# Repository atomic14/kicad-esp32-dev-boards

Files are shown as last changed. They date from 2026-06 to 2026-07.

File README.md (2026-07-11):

# ESP Dev-Board Generator

Generates canonical "basic dev board" KiCad schematics for the Espressif modules
that have a **PCB antenna + native USB** (12 modules across S2/S3/C3/C5/C6/H2).
Each board takes a shared skeleton (USB-C, 3V3 LDO, BOOT/EN buttons, LEDs) and
adds the module symbol + two break-out pin headers, wired entirely with net
labels (no routing). Output is a complete, openable KiCad project per module.

> **Why / design rationale:** see [`DECISIONS.md`](DECISIONS.md). This file is
> the *operational* guide; DECISIONS.md is the *why*.

## What it builds

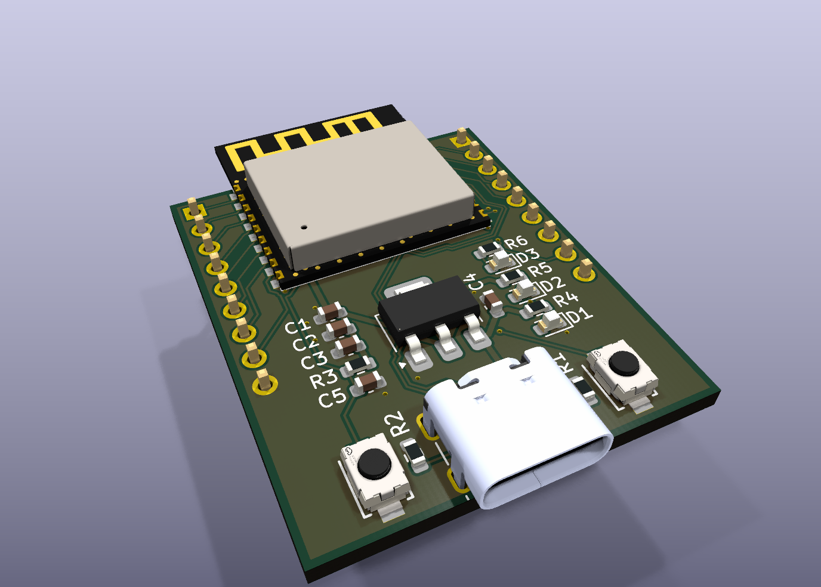
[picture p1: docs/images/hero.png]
ESP32-C3-WROOM-02 dev board, 3D render


Every board is the same canonical dev board — USB-C, 3V3 LDO, BOOT/EN buttons,
power + user LEDs — plus the module and its full GPIO break-out on two headers
(that's the ESP32-C3-WROOM-02 above; every component carries its 3D model, so
each board renders assembly-ready). The views below are to scale (equal
mm-per-pixel; each label carries the board's WxH):

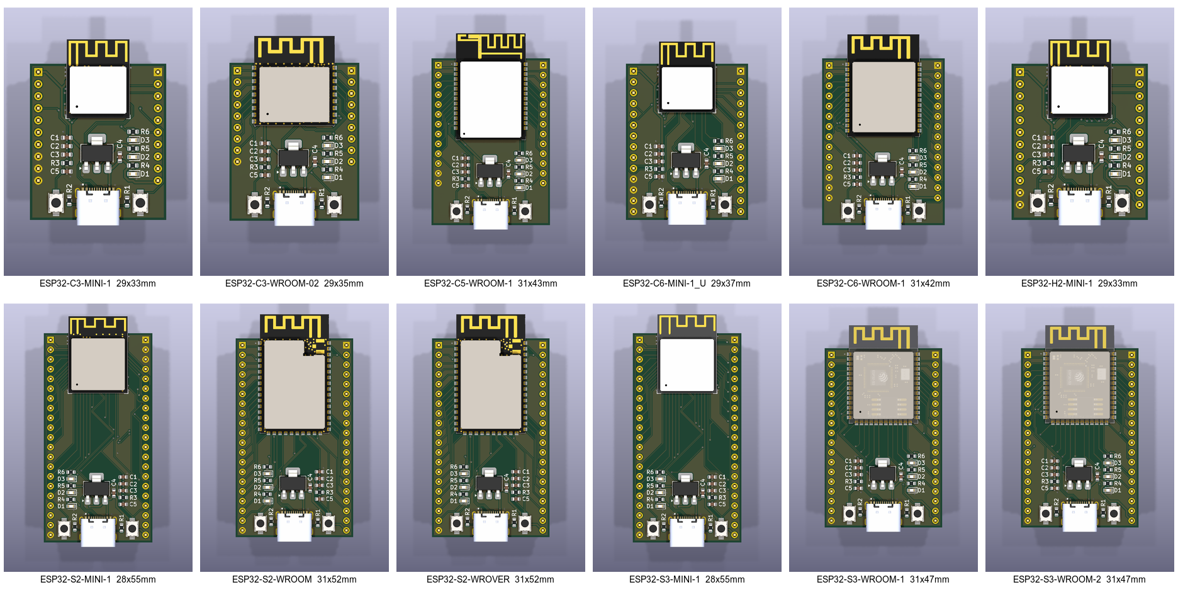
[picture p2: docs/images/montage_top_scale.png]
All 12 boards, front, to scale


The back silk labels every header pin with its net name and carries a vertical
board identifier — the module name plus the git revision that generated it
(`git describe --tags --always --dirty`):

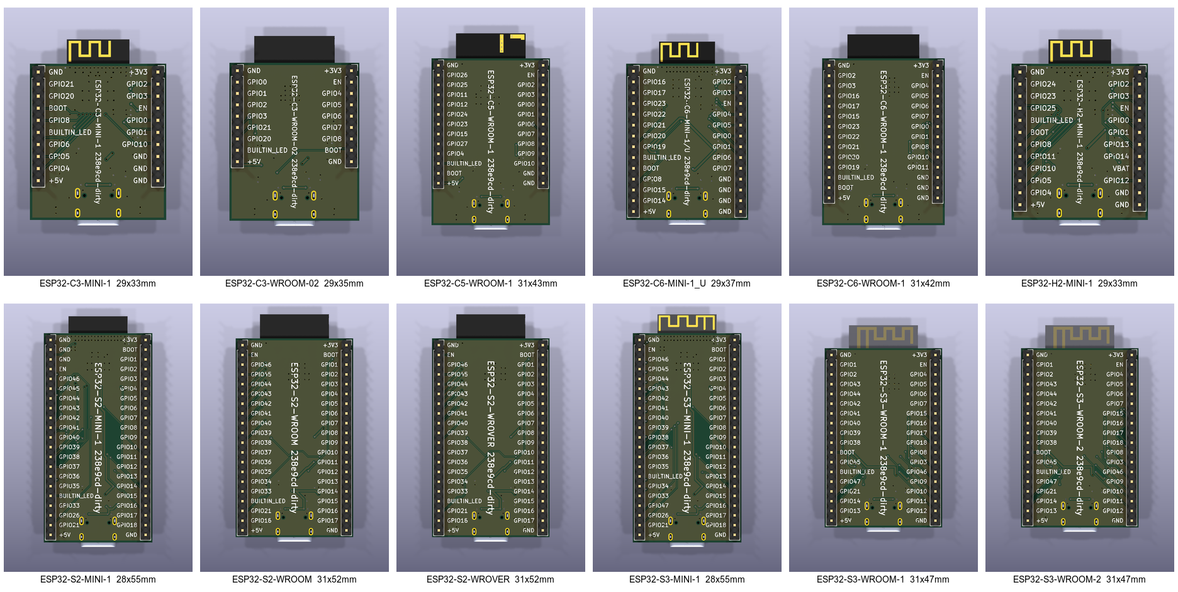
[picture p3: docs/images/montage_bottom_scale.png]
All 12 boards, back, to scale


These are snapshots of what `make.py --render` writes to `build/`: seven
montages (`montage_{top,top_bare,bottom}[_scale].png` — auto-fit and to-scale —
plus `montage_hero.png`) and a perspective `render_hero.png` per board under
`build/<MODULE>/`. To refresh them:

```bash
cp build/montage_{top,bottom}_scale.png docs/images/
cp build/ESP32-C3-WROOM-02/render_hero.png docs/images/hero.png
```

## Prerequisites (per machine)

1. **KiCad 10.x** installed (the schematics use the v10 file format).
2. **Espressif KiCad libraries installed *for that same KiCad version*** via
   KiCad's **Plug-in & Content Manager** (open KiCad 10 → PCM → search
   "Espressif" → install "Espressif KiCad Libraries" → Apply). This provides the
   `PCM_Espressif` symbol/footprint libraries. *This is the one manual install
   step and must be done before running anything.*
   > ⚠️ The addon is installed **per KiCad major version**. Having it for
   > KiCad 8/9 does **not** count if you run KiCad 10 — the PCM stores each
   > version's addons under a separate `Documents/KiCad/<version>/3rdparty` dir.
   > `resolve_library.py` pins to your running `kicad-cli` version and will
   > **hard-fail** (with these instructions) if the addon is missing for it,
   > rather than silently mixing libraries across versions.
3. **[uv](https://docs.astral.sh/uv/)** (Python package manager).
4. **[KiCadRoutingTools](https://github.com/atomic14/KiCadRoutingTools)** (our
   fork, `dev-board-fixes` branch) cloned as a **sibling** of this repo (or set
   `$KICAD_ROUTING_TOOLS`), with its Rust router built:
   ```bash
   git clone -b dev-board-fixes https://github.com/atomic14/KiCadRoutingTools.git ../KiCadRoutingTools
   (cd ../KiCadRoutingTools && python3 build_router.py --from-source)  # needs cargo
   ```
   Only needed for the *route* stage — build/render/fab work without it.
5. Internet access to `https://www.atomic14.com/esp32/` (only needed when
   curating a new module's `board.yaml`).

`resolve_library.py` auto-locates KiCad on macOS / Linux / Windows. If it can't,
set `ESPRESSIF_3RDPARTY` (the `<kicad>/3rdparty` dir) and/or `KICAD_CLI`
(path to `kicad-cli`) and re-run it. **Re-run it after any KiCad upgrade /
reinstall** — `library.json` records absolute, version-specific paths, and
`make.py` will refuse to run (pointing you back here) if those paths go stale.

## Quick start

```bash
uv sync                                   # restore the Python env (pinned in uv.lock)
uv run python scripts/resolve_library.py  # detect KiCad/libraries -> library.json (once/machine)
uv run python scripts/make.py             # build + route every board (THE command)
```

`make.py` is the one front door — it chains clean → build → route → render:

```bash
uv run python scripts/make.py            # build + route all modules
uv run python scripts/make.py --clean    # wipe prior output first
uv run python scripts/make.py --render    # also render the 3D montages
uv run python scripts/make.py --fab       # also export fab zips (Gerbers + drill)
uv run python scripts/make.py --all       # clean + build + route + render + fab
uv run python scripts/make.py --no-route  # build only
```

Generated boards land in `out/<MODULE>/<MODULE>.kicad_sch` (+ `.kicad_pro`,
`.kicad_pcb`); validation artifacts (ERC JSON, PDF render) in `build/<MODULE>/`.
Open any `out/<MODULE>/<MODULE>.kicad_pro` in KiCad. Both `out/` and `build/` are
git-ignored and fully disposable — `make.py --clean` (or `clean.py`) just removes
them. The curated source in `modules/` is never touched.

## Repository layout

```
DECISIONS.md            design decisions + rationale (read for the "why")
library.json            GENERATED per machine by resolve_library.py (git-ignore-able)
pyproject.toml/uv.lock  pinned Python env (kicad-skip, sexpdata, pyyaml)
baseline-left-en/       skeleton KiCad project (INPUT — never edit); EN button on the left
baseline-right-en/      same skeleton mirrored, EN on the right — generator auto-picks per module
  BasicEsp32Footprints.pretty/, 3d-models/, fp-lib-table   project-local footprints + 3D models
scripts/                orchestrators (run these); scripts/lib/ holds the per-module primitives
modules/<MODULE>/        CURATED SOURCE only (committed) — clean never touches it
  board.yaml            the only hand-authored file (see below)
  pinout.json           extracted from the symbol (never hand-edit); cached source
out/<MODULE>/            GENERATED board (git-ignored, disposable: rm -rf out)
  <MODULE>.kicad_sch/pro/pcb   the board — open <MODULE>.kicad_pro in KiCad
  fp-lib-table + *.pretty/ + asset dirs   copied from baseline
  route_debug/          per-stage routing snapshots for inspection
  fab/ + <MODULE>-fab.zip   Gerbers + Excellon drill; the .zip is fab-ready
build/<MODULE>/          GENERATED validation artifacts (git-ignored, disposable)
docs/AGENT_END_TO_END.md  agent spec: curate every board.yaml, then pilot-verify one module
docs/images/             committed montage snapshots referenced by this README

```

## The pipeline (`scripts/`)

**Orchestrators** — the top-level commands you run:

| Script | Role | Deterministic? |
|---|---|---|
| `make.py` | **THE command** — chains clean → build → route → render → fab (flags toggle stages) | ✅ |
| `resolve_library.py` | Find KiCad libs + `kicad-cli` → `library.json` | ✅ run once/machine |
| `build_all.py [--clean]` | extract → build → validate every curated module | ✅ |
| `route_all.py [--no-diff]` | autoroute every board (diff-pair with single-ended fallback; writes back in place) + DRC | ✅ |
| `render_boards.py` | 3D montages of every board → `build/` (top, top-bare/no-components, bottom — each auto-fit AND to-scale — plus a perspective hero shot per board) | ✅ |
| `fab_all.py` | Gerber + Excellon drill zip per board → `out/<M>/<M>-fab.zip` | ✅ |
| `clean.py` | remove generated output for a fresh run — just `rm -rf out build`; the curated `modules/` source is never touched | ✅ |

**Primitives** (`scripts/lib/`) — operate on one module; called by the orchestrators, rarely run directly:

| Script | Role |
|---|---|
| `extract_pinout.py "<MODULE>"` | Parse the symbol → `modules/<m>/pinout.json` |
| `footprint_edges.py "<MODULE>"` | Physical pin edges from the footprint |
| `build_board.py "<MODULE>"` | **The generator**: module + perimeter-split headers + labels + footprints + project files (copies the baseline's `fp-lib-table` and all asset dirs — `*.pretty` footprint libs, `3d-models/`, etc.) |
| `route_board.py "<MODULE>"` | Autoroute one board (USB-C fine neck, signals, GND pour) |
| `place_pcb.py` / `gnd_finish.py` / `gnd_prestitch.py` | PCB placement + GND-pour fill/stitch helpers (prestitch protects GND pads before routing) |
| `validate.py <sch>` | ERC delta vs baseline + PDF render |
| `fab_export.py "<MODULE>"` | Gerbers (`--check-zones` refills pours) + Excellon drill → zipped fab package |

**~95% of the work is fully scripted.** The only step needing human/agent
judgement is curating each module's `board.yaml`.

## Adding / re-curating a module

`board.yaml` is the one hand-authored file. Most wiring is auto-derived (power,
GND, EN, USB→D±, GPIO→`GPIOxx` labels). You decide:

- **`do_not_break_out`**: pins that must NOT be exposed — internal flash/PSRAM
  and any pin the [atomic14 module page](https://www.atomic14.com/esp32/modules/)
  marks as a hard "do not use". Strapping / JTAG / UART / USB pins are still
  broken out (documented in `notes`, not excluded).
- **`strapping` / `input_only`**: GPIO numbers (curated from the atomic14 page /
  datasheet) that are sampled at reset or have no output driver. They're *still*
  broken out — these lists only steer the on-board LED away from unsafe pins.
- **`builtin_led`**: the GPIO the skeleton's on-board LED attaches to. The
  generator routes it to the **safe pad physically nearest the LED** on the laid-out
  PCB (shortest trace); `build_board.py pick_builtin_led()` computes exactly that,
  and the build **hard-errors** if `builtin_led` names a strapping / input-only /
  non-broken-out pin. "Safe" = I/O-capable, non-strapping, broken-out GPIO.
- **`boot`**: the download/boot strapping GPIO the on-board BOOT button pulls low —
  GPIO0 on Xtensa (ESP32/-S2/-S3), GPIO9 on most RISC-V (-C3/-C6/-H2), GPIO28 on
  -C5. Varies per module, so the generator aliases the skeleton's `BOOT` net onto it.

```yaml
module: ESP32-S3-WROOM-1
symbol: PCM_Espressif:ESP32-S3-WROOM-1
do_not_break_out: [SPIDQS, SPIIO6, SPIIO7]   # octal flash/PSRAM, must not expose
overrides: {}
strapping: [0, 3, 45, 46]   # sampled at reset — unsafe for the LED (GPIO45 = VDD_SPI)
input_only: []              # no output driver
builtin_led: GPIO48         # safe GPIO pad nearest the on-board LED (NOT GPIO45, a strap)
boot: GPIO0                 # download/boot strapping pin the BOOT button pulls low
notes: >
  Source: https://www.atomic14.com/esp32/modules/esp32-s3-wroom-1/ ...
```

> ⚠️ Curation is **symbol-specific, not name-based**: e.g. `SPIIO6/7`/`SPIDQS`
> are reserved on the octal S3-WROOM-1, but are *freely-usable GPIO* on the quad
> S3-MINI-1 (and are NC, so absent, on the WROOM-2). Check the atomic14 page;
> don't blindly exclude by name.

Then: `uv run python scripts/lib/build_board.py "<MODULE>"` and
`uv run python scripts/lib/validate.py out/<m>/<m>.kicad_sch`, and **open the
rendered PDF** — the visual check catches things ERC can't (it once passed a
board whose USB pins were unconnected).

## Validation

`validate.py` gate = **no new ERROR-severity ERC violations vs the baseline**.
New *warnings* are expected and fine (notably the `pin_to_pin` from connecting
`GPIO0` to the boot button — the EasyEDA button symbol uses `Unspecified` pin
types). The baseline itself has ~58 pre-existing violations, so the bar is the
*delta*, not zero. Always also eyeball the PDF render.

## Fabrication

`make.py --fab` (or `fab_all.py`, or `fab_export.py "<M>"` for one) exports a
fab-ready package per board to `out/<M>/<M>-fab.zip` (loose files also in
`out/<M>/fab/`). The zip holds the standard 2-layer Gerber set (`F.Cu B.Cu`,
paste, silkscreen, mask, `Edge.Cuts`) plus an Excellon drill file, drill map,
and `.gbrjob` — flat-zipped, ready to upload to JLCPCB / PCBWay / most houses.

Key detail: the Gerber export runs with `--check-zones`, which **refills the
copper pours during export**, so the GND plane is always present in the copper
Gerbers even though headless tools save boards with empty fills — otherwise
you'd ship a board with no ground plane. Coordinates use an absolute origin for
both Gerbers and drill so they align. If your fab wants PTH/NPTH drills split,
add `--excellon-separate-th` in `fab_export.py` (currently combined).

**Silk order-number marker.** `build_board` drops a small F-silk text
(`SILK_MARKER_TEXT`, default `"WayWayWay"`) centred in the clear band just above
the module's bottom pin row — under the body, so it's hidden once the module is
soldered down, and never on exposed copper (its real rendered bounding box is
clearance-checked against every pad, and the size auto-shrinks on tight modules).
This gives the board house a designated spot for its order number instead of it
landing on visible silk. Change the text via `SILK_MARKER_TEXT` in `place_pcb.py`.

**Back-silk board identifier.** Each board also gets a vertical B-silk text
centred on the back: `"<module> <git describe --tags --always --dirty>"` — so a
physical board always names its module and the exact repo revision that
generated it. Tag the repo (e.g. `v1.0`) to get a clean rev number on the silk;
between tags it reads `v1.0-3-g<hash>`, and `-dirty` flags uncommitted changes.
The text auto-sizes to the board height (1.5 mm down to a 0.8 mm floor,
dropping the revision before the name if it can't fit) — see
`place_pcb.board_id_text`.

## CI / Releases

`.github/workflows/build.yml` runs the whole pipeline on GitHub Actions
(Ubuntu): KiCad 10 from the official PPA, the Espressif PCM addon unpacked
headlessly into the layout `resolve_library.py` expects, then
`xvfb-run make.py --all`. Every push to `main` uploads the boards as a
workflow artifact; pushing a version tag (`git tag v1.1 && git push --tags`)
additionally publishes a GitHub **release** with the per-board fab zips, KiCad
project zips, and the montages attached. Boards built from a tag carry that
version on their back silk (the identifier bakes in `git describe`).

## Handoff notes

To pass this on: ship the whole directory **except `.venv/`** (regenerated by
`uv sync`) and `library.json`/`out/`/`build/` (regenerated per machine). The
recipient runs the three Quick-start commands. The curated `modules/<M>/board.yaml`
(+ `pinout.json`) are the valuable hand-work and are the only committed per-module
files.

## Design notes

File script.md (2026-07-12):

# "I Asked AI to Design 12 Circuit Boards. It Told Me Not To."

> YouTube script — maker-friendly, ~10 min.
> Spine: *one command, 12 boards.* Thesis: *the skill is knowing where AI does
> NOT belong.* Scripts do the mechanical 95%; an LLM does the one judgement step
> (reading the atomic14 module pages into each board's `board.yaml`).

---

## 1 · COLD OPEN — 0:00

**[SCREEN: the actual Claude conversation — the "team of agents" ask and the refusal. This is the money shot for the title.]**

I wanted a dev board for every single ESP32 module. All twelve of them.

So I did what everyone on the internet is telling you to do right now — I asked Claude to spin up a *team of AI agents* to design the boards for me.

And it said: "No."

It was very nice about it, but it basically said: "You're wasting my time and your own — this is not an AI problem. You don't want a swarm of agents randomly wiring things up. You want some deterministic scripts."

So I let it write those instead.

**[SCREEN: black terminal, big font. Type `uv run python scripts/make.py --all`, hit enter. Time-lapse of boards rendering one after another — then a grid of all 12 finished boards rotating in 3D (the hero montage).]**

And there we go. Twelve fully routed dev boards, from one command. Let me show you why the AI was right to turn the job down.

---

## 2 · THE PROBLEM — ~0:45

**[SCREEN: a dev board close-up, parts highlighting as you name them.]**

I've built a few Espressif dev boards, and they always end up pretty similar.

You have the USB-C port with its 5.1K resistors.

You have the 3.3 volt regulator along with a bunch of decoupling capacitors.

Two buttons — one to control boot mode and another to reset the module.

Some LEDs.

And of course the pin headers to break out the GPIO pins.

**[SCREEN: the Espressif module line-up — S2, S3, C3, C5, C6, H2 — photos or the module pages.]**

**VO:** Espressif make about a dozen modules with a PCB antenna and native USB, and I wanted that same board for every one of them. The only things that really differ are the number of pins on the headers, the size of the module, the positions of everything — and the actual routing of the copper.

**VO:** So that's the *same boring board* twelve times. And boring, repetitive work is exactly where humans make mistakes. Wire the LED to the wrong pin on board number nine at midnight and you won't find out until the thing won't boot.

**TO CAMERA:** This is the kind of job you *should* automate. The question is *how*.

---

## 3 · THE PRINCIPLE — ~2:00

**[SCREEN: split screen. Left: a workshop jig. Right: a person reading a datasheet.]**

**VO:** There are two completely different kinds of tool here, and the whole project comes down to telling them apart.

**VO:** The first is a *jig*. Same input, same output, every single time. Free, instant, perfectly repeatable. A script is a jig. I can run it, wipe everything, and run it again — and get byte-for-byte identical boards.

**VO:** The second is more like an *apprentice* you send off to read the datasheet and come back with notes. Slower. Costs you something every time. And it might get it slightly wrong. That's a language model.

**TO CAMERA:** Now imagine putting an AI in the middle of that loop. Every run gets slower. Every run costs money. And worst of all — one day it'll wire something wrong, *quietly*, and I'll never know. A script can't do that. It's too boring to make mistakes — it does exactly the same thing, every single time. So here's the deal I settled on: the AI gets *one* file per board — the one file that actually needs a brain. Everything else is a jig.

---

## 4 · THE REVEAL — ~3:30

**[SCREEN: the terminal, run `make.py` for real. Let the stages scroll.]**

**VO:** So here's the one command. All it's really doing is a handful of steps, in order. Build the schematic. Place the parts on the board. Route the copper. Render a picture so I can check it. And zip up the files the factory needs.

**[SCREEN: open one generated board in KiCad, spin the 3D view. Zoom the ground pour and the fat power traces.]**

**VO:** No mouse. No dragging traces. We've got ground pours, thick 0.4 millimetre tracks for power, and the USB data lines routed as a differential pair. That's not a mock-up — it's a real, manufacturable board I could send off and get back in the post.

---

## 5 · HOW IT WORKS — THE LEGO BIT — ~4:45

**[SCREEN: the bare skeleton board (USB-C, regulator, buttons, LEDs) on its own.]**

**VO:** The trick is that I'm not designing twelve boards. I'm designing *one* — a skeleton with all the stuff every board needs. The USB-C, the power, the buttons, the LEDs.

**[SCREEN: same skeleton, drop in three different modules + header strips.]**

**VO:** Then the generator snaps in the module and two header strips, draws the board outline to fit, and wires it all up with net labels. Automatically.

**[SCREEN: two skeletons side by side — mirror images. Highlight the reset button on one side, the boot button on the other; then flip.]**

**VO:** And here's a detail I really like. On some of these modules the **reset pin and the boot pin swap sides** — what's on the left of one module is on the right of another. Use a single fixed layout and half the boards end up with long, ugly traces snaking across to reach a button.

**VO:** So I keep *two* versions of the skeleton — mirror images of each other. The generator looks at which side the reset pin comes out on and picks the matching baseboard, so the buttons always sit right next to their pins. A human would just eyeball that. The script makes the same call, the same way, every time.

**[SCREEN: flip a board over — zoom the vertical silk text down the middle of the back: "ESP32-S3-MINI-1 v1.0".]**

**VO:** And the jig signs its work. Every board gets the module name and the exact git revision that generated it, printed down the back in silkscreen. If one of these turns up in a drawer in five years, the board itself tells you precisely which version of the scripts made it.

---

## 6 · WHERE THE AI ACTUALLY LIVES — ~6:15

**[SCREEN: open a single `board.yaml`, highlight the `boot` field.]**

**VO:** So where's the AI in all this? Right here. This little file. It's the *only* thing on each board that's written by hand — or rather, the only thing the AI writes.

**VO:** Some decisions you genuinely can't script. Which pins are safe to break out, and which are off-limits because they're wired to the module's internal flash. Which pins the chip reads at power-up, so the on-board LED mustn't sit on them. And this one: the **boot pin**.

**VO:** When you power up an ESP32, one special pin decides what it does — boot normally from flash, or drop into programming mode so you can upload new code. That's what the boot button on every dev board is for. But *which* GPIO does that job **changes depending on the chip** — it's one pin on the older Xtensa chips, a different one on most of the RISC-V chips, and different again on the C5.

**[SCREEN: your atomic14.com/esp32 module page.]**

**VO:** And all of that — which pin, on which chip, which pins to leave alone — is written in plain English on my Espressif module information site, for humans. So that's the job I hand to the AI: read the page for this module, and fill in this file. Messy human writing in, clean data out. That is the one thing a script can't do and a language model can.

**TO CAMERA:** That's the whole philosophy. The AI proposes. The jig verifies.

---

## 7 · GUARDRAILS — "AI PROPOSES, THE JIG VERIFIES" — ~7:30

**[SCREEN: deliberately set the builtin LED to a strapping pin, run the build, show the hard error.]**

**VO:** Watch this. The on-board LED can't go on just *any* pin. Some pins are "strapping" pins — the chip reads them at power-up to decide how to boot. Put your LED on one of those and the board won't flash properly.

**[SCREEN: the build aborts with the error.]**

**VO:** So if the AI suggests a bad pin, the build just... refuses. It won't generate the board. The robot stops me making the mistake. That's the safety net under the AI — and it's why I'm comfortable letting it near this at all.

---

## 8 · HONESTY BEAT 1 — THE LOG THAT NEARLY FOOLED ME — ~8:15

**[SCREEN: zoom in on the USB D+/D- traces — two tracks running perfectly parallel from the USB-C up to the module.]**

**VO:** Now let me be honest about where this got hard: the routing. I found a really nice tool for this — KiCadRoutingTools. You can drive it from inside KiCad as a plugin, or just call its scripts, which is exactly what a jig wants. Claude and I spent a while getting it dialled in across all twelve boards.

**VO:** The USB data lines — D-plus and D-minus — are a *differential pair*. Best practice is to route them together, matched, side by side. And look — that's exactly what it does. On every one of the twelve boards, those two tracks run coupled, fifteen hundredths of a millimetre apart, all the way from the connector to the module.

**[SCREEN: the router's log — "deferred to single-ended ['D+', 'D-']" highlighted. Big red circle.]**

**VO:** But here's the bit that nearly caught me out. When I read the router's log, I found *this* — "deferred to single-ended, D-plus, D-minus". I read that and thought the pair had failed. I was halfway through writing "the automation lost this fight" before I went and actually *measured the copper*.

**VO:** The pair was fine. That message is about a couple of *millimetre-long* stubs at the connector itself — the USB-C has two pads for each data line, and the router is smart enough to know that coupling a one-millimetre pad bridge is meaningless, so it finishes those tiny legs individually. The main run — the bit that matters — is a textbook coupled pair on every single board.

**TO CAMERA:** So the automation was right, and *I* was the unreliable component — I trusted a log line instead of the board. Hold that thought, because it's about to become a theme.

---

## 9 · HONESTY BEAT 2 — THE GREEN CHECK THAT LIED — ~9:00

**[SCREEN: the electrical check passing — a green result.]**

**VO:** One more, because this one taught me a lesson. Early on, the automated electrical check came back completely clean. Green across the board.

**[SCREEN: the render showing the USB pins unconnected.]**

**VO:** And the board was *dead*. The USB pins weren't actually connected to anything. The checker was happy. The board was useless.

**TO CAMERA:** So now, every board gets a picture rendered at the end — and I *look* at it. That's the real lesson here. Automation gets you ninety-five percent of the way. The last five percent is still you, looking at the thing with your own eyes.

---

## 10 · CLOSE — ~9:45

**[SCREEN: the grid of 12 boards again, then the fab zips landing in the terminal.]**

**VO:** So — twelve boards, one command. Every one of them passes the design rule check with zero errors, and the Gerbers come out the other end zipped up and ready to send to the fab. Scripts do the boring, mechanical ninety-five percent. The AI does the one bit that needs judgement: reading the docs and writing the notes. And a set of guardrails makes sure it can't hurt anything.

**[SCREEN: the GitHub Actions run going green, then the release page with all the zips.]**

**VO:** In fact, it doesn't even need my computer any more. The whole pipeline runs on GitHub's servers — every change rebuilds all twelve boards from scratch inside a KiCad container, and tagging a release publishes the Gerbers and the KiCad projects automatically. You don't have to run anything: the files you'd send to the fab are sitting on the releases page right now.

**TO CAMERA:** The lesson I actually want you to take away isn't "use AI." It's the opposite. The clever part was working out where *not* to. Even the AI knew that before I did.

**[SCREEN: repo link / atomic14 lower-third.]**

**TO CAMERA:** So — over to you. Which of these boards should we actually get manufactured? What would you like to see? Tell me in the comments. Everything's on GitHub, link below — and there's a whole other video in *how* the AI fills in that one file from the website, so let me know if you want that one too. Cheers.

**[END CARD.]**

---

## Shot list (film while it's fresh)

- The Claude "no" conversation for the cold open — screenshot or screen recording.
- The `make.py --all` time-lapse — the money shot. Film it clean.
- The hero montage (`build/montage_hero.png`) and the to-scale montages
  (`montage_top_scale.png` / `montage_bottom_scale.png`) for the grid shots —
  the to-scale ones make the size differences land.
- Component close-ups for beat 2 (USB-C, regulator, buttons, LEDs, headers).
- Two mirrored baseboards, reset/boot buttons swapping sides (beat 5).
- The back-silk version stamp (beat 5) — flip to the bottom view, zoom the
  vertical "ESP32-S3-MINI-1 v1.0" text between the pin-label columns.
- One `board.yaml` on screen — the only hand-authored file (beat 6).
- The LED safety hard-error firing live (beat 7).
- Beat 8 needs BOTH shots: the coupled D+/D- pair zoomed on the board (two
  parallel tracks, USB-C to module) AND the misleading log line `deferred to
  single-ended ['D+', 'D-']` (run `scripts/lib/route_board.py` on a freshly
  built board to capture it live).
- The "green check that lied" — passing ERC next to the render with unconnected USB pins (beat 9).
- Ground pour + 0.4mm power traces zoom (beat 4).
- GitHub Actions run going green + the v1.0 release page with 24 zips (close).

## Accuracy notes (don't contradict the code on camera)

- **Baseboard mirror (beat 5)** = *physical layout*. The EN (reset) and BOOT pins
  swap sides as a pair between module families; the generator keys the choice off
  the **EN pin's** edge (`build_board.py: baseline_dir`) and picks `baseline-left-en`
  or `baseline-right-en`. No GPIO numbers here.
- **Boot pin (beat 6)** = *logical*. The `board.yaml` `boot` field — which GPIO
  the boot button pulls low for programming-vs-flash. GPIO0 on Xtensa (S2/S3),
  GPIO9 on most RISC-V (C3/C6/H2), GPIO28 on C5. This does NOT affect baseboard
  selection.
- **USB speed (beat 8)**: ESP32 native USB is **full-speed (12 Mbps)** — never say
  "high speed" on camera; the point is that full-speed is *forgiving* of an
  unmatched pair, not that high speed is.
- **Diff pair (beat 8) — measured on the copper, 2026-07-12**: ALL 12 boards
  route D+/D- as a proper coupled pair — 92–96% of the D+ track length runs
  at 0.30 mm centre-to-centre (0.15 track + 0.15 gap) from D- on the same
  layer. The log line `deferred to single-ended ['D+', 'D-']` refers ONLY to
  the millimetre-scale legs at the USB-C's duplicated pads (A6/B6, A7/B7 —
  multi-point nets); the router couples the long leg and finishes the short
  pad bridges single-ended. Do NOT say the pair failed, fell back, or was
  declined — the beat is now "I misread the log; the copper was right."
  (Verify script: measure D+ segments' distance to same-layer D- segments in
  the .kicad_pcb — see the coupling check used on 2026-07-12.)
- **Zero errors (beat 10)** = *DRC on the PCB*. Don't claim zero **ERC**
  violations — the skeleton ships with ~58 pre-existing ones by design; the gate
  is "no *new* errors."
- The router is **KiCadRoutingTools by drandyhaas** (github.com/drandyhaas/
  KiCadRoutingTools) — credit him on camera. We run a pinned fork
  (atomic14/KiCadRoutingTools, `dev-board-fixes`) that adds one small feature:
  keeping vias out of same-net SMD pads (`--same-net-pad-clearance`).
- **The one command (beats 1/4/10)**: plain `make.py` only builds + routes.
  Renders and fab zips need `--render`/`--fab` — on camera, type
  **`make.py --all`** so the montage + zips shown actually come from that run.
- **"Byte-for-byte identical" (beat 3)**: true at a given commit (UUIDs are
  deterministic) — but the back silk bakes in `git describe`, so boards from
  different commits differ by exactly that stamp. Say "run it twice, get the
  same boards"; avoid "next year" unless you add "from the same commit".
- **Back-silk stamp (beat 5)**: text is `<module> <git describe>` — e.g.
  `ESP32-S3-MINI-1 v1.0` from the tag, `...v1.0-2-gc9c8c5d` between tags,
  `-dirty` with uncommitted changes. Film a board built from the v1.0 tag for
  a clean stamp.
- **CI (close)**: runs in the official `kicad/kicad:10.0-full` Docker image;
  a `v*` tag publishes the release (12 fab zips + 12 project zips + montages).
  Releases page: github.com/atomic14/kicad-esp32-dev-boards/releases.

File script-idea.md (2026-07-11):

# "I Asked AI to Design 12 Circuit Boards. It Told Me Not To."

> YouTube script — maker-friendly, ~10 min.
> Spine: *one command, 12 boards.* Thesis: *the skill is knowing where AI does
> NOT belong.* Scripts do the mechanical 95%; an LLM does the one judgement step
> (reading the atomic14 module pages into each board's `board.yaml`).

---

## 1 · COLD OPEN — 0:00

**[SCREEN: black terminal, big font. You type `uv run python scripts/make.py`, hit enter. Hold on the first log lines.]**

I wanted to design a dev board for every single ESP32 module.

So, I did what everyone on the internet is telling you to do right now. I asked the AI to spin up a *team of agents* to design the boards for me.

It's response was - stop wasting my time - this is a mechanical job. You don't want a swarm of agents randomly wiring things up, you want some deterministic scripts.

So I let it write those for me.

**[CUT TO: the terminal time-lapse — boards rendering one after another — then a grid of all 12 finished boards rotating in 3D.]**

And there we go twelve nice little fully routed dev boards.

## 2 · THE PROBLEM — ~0:45

**[SCREEN: the Espressif module line-up — S2, S3, C3, C5, C6, H2 — photos or the module pages.]**

**VO:** Here's the job. Espressif make about a dozen modules with a PCB antenna and native USB. And for every single one of them, I wanted the same thing: a basic dev board. USB-C in, a 3-volt-3 regulator, a reset button, a boot button, a couple of LEDs, and all the pins broken out to headers.

**[SCREEN: a hand-drawn or animated dev board, parts highlighting as you name them.]**

**VO:** Now — that's the *same boring board* twelve times. And boring, repetitive work is exactly where humans make mistakes. Wire the LED to the wrong pin on board number nine at midnight and you won't find out until the thing won't boot.

**TO CAMERA:** This is the kind of job you *should* automate. The question is *how*.

---

## 3 · THE PRINCIPLE — ~2:00

**[SCREEN: split screen. Left: a workshop jig. Right: a person reading a datasheet.]**

**VO:** There are two completely different kinds of tool here, and the whole project comes down to telling them apart.

**VO:** The first is a *jig*. Same input, same output, every single time. Free, instant, perfectly repeatable. A script is a jig. I can run it today, run it next year, and get byte-for-byte identical boards.

**VO:** The second is more like an *apprentice* you send off to read the datasheet and come back with notes. Slower. Costs you something every time. And it might get it slightly wrong. That's a language model.

**TO CAMERA:** An AI in the middle of my routing loop would be slow, it'd cost money on every run, and it might *quietly* wire something wrong and never tell me. A script doesn't improvise. So I decided the AI gets to touch *one* file — the one file that actually needs a brain. Everything else is jigs.

---

## 4 · THE REVEAL — ~3:30

**[SCREEN: the terminal, run `make.py` for real. Let the stages scroll.]**

**VO:** So here's the one command. And all it's really doing is four steps, in order. Build the schematic. Place the parts on the board. Route the copper. And render a picture so I can check it.

**[SCREEN: open one generated board in KiCad, spin the 3D view.]**

**VO:** No mouse. No dragging traces. And that's not a mock-up — that's a real, manufacturable board I could send off and get back in the post.

---

## 5 · HOW IT WORKS — THE LEGO BIT — ~4:45

**[SCREEN: the bare skeleton board (USB-C, regulator, buttons, LEDs) on its own.]**

**VO:** The trick is that I'm not designing twelve boards. I'm designing *one* — a skeleton with all the stuff every board needs. The USB-C, the power, the buttons, the LEDs.

**[SCREEN: same skeleton, drop in three different modules + header strips.]**

**VO:** Then the generator snaps in the module and two header strips, and wires it all up automatically.

**[SCREEN: two skeletons side by side — mirror images. Highlight the reset button on one side, the boot button on the other; then flip.]**

**VO:** And here's a detail I really like. On some of these modules the **reset pin and the boot pin swap sides** — what's on the left of one module is on the right of another. So if I used a single fixed layout, half the boards would end up with long, ugly traces snaking across to reach a button.

**VO:** So I keep *two* versions of the skeleton — mirror images of each other. On one, the reset button's on the left and boot's on the right; on the other, they're flipped. The generator looks at which side those pins come out on and picks the matching baseboard, so the buttons always sit right next to their pins. A human would just eyeball that. The script makes the same call, the same way, every time.

---

## 6 · WHERE THE AI ACTUALLY LIVES — ~6:15

**[SCREEN: open a single `board.yaml`, highlight the `boot` field.]**

**VO:** So where's the AI in all this? Right here. This little file. It's the *only* thing on each board I write by hand — or rather, the only thing the AI writes.

**VO:** Some decisions you genuinely can't script. Which pins are safe to expose, which are off-limits because they're wired to internal flash — and this one: the **boot pin**.

**VO:** When you power up an ESP32, one special pin decides what it does — boot normally from flash, or drop into programming mode so you can upload new code. That's what the boot button on every dev board is for. But *which* GPIO does that job **changes depending on the chip** — it's one pin on the older Xtensa chips, a different one on most of the RISC-V chips, and different again on the C5.

**[SCREEN: your atomic14.com/esp32 module page.]**

**VO:** And all of that — which pin, on which chip — is written in plain English on my website, for humans. So that's the job I hand to the AI: read the page for this module, and tell me which pin is the boot pin. Messy human writing in, clean data out. That is the one thing a script can't do and a language model can.

**TO CAMERA:** That's the whole philosophy. The AI proposes. The jig verifies.

---

## 7 · GUARDRAILS — "AI PROPOSES, THE JIG VERIFIES" — ~7:30

**[SCREEN: deliberately set the builtin LED to a strapping pin, run the build, show the hard error.]**

**VO:** Watch this. The on-board LED can't go on just *any* pin. Some pins are "strapping" pins — the chip reads them at power-up to decide how to boot. Put your LED on one of those and the board won't flash properly.

**[SCREEN: the build aborts with the error.]**

**VO:** So if the AI suggests a bad pin, the build just... refuses. It won't generate the board. The robot stops me making the mistake. That's the safety net under the AI — and it's why I'm comfortable letting it near this at all.

---

## 8 · HONESTY BEAT 1 — THE DIFF-PAIR COMPROMISE — ~8:15

**[SCREEN: zoom in on the USB D+/D- traces on a board, ideally a clean diff pair.]**

**VO:** Now let me be honest about where this got hard. The USB data lines — D-plus and D-minus — are a *differential pair*. Best practice is to route them together, matched, side by side. So that's what I told the router to do on every board.

**[SCREEN: a board where they fell back to single-ended.]**

**VO:** And on most boards, it nailed it. But on a few of the tighter, more crowded ones, the autorouter just *couldn't* complete the pair — there wasn't room to keep them together all the way. So rather than fail, it falls back and routes them individually.

**TO CAMERA:** Is that perfect? No. A pro doing USB at high speed would care. For a basic dev board at USB full-speed, it's absolutely fine. But I'm not going to stand here and pretend the automation won every fight — it didn't, and it tells you when it compromised.

---

## 9 · HONESTY BEAT 2 — THE GREEN CHECK THAT LIED — ~9:00

**[SCREEN: the electrical check passing — a green result.]**

**VO:** One more, because this one taught me a lesson. Early on, the automated electrical check came back completely clean. Green across the board.

**[SCREEN: the render showing the USB pins unconnected.]**

**VO:** And the board was *dead*. The USB pins weren't actually connected to anything. The checker was happy. The board was useless.

**TO CAMERA:** So now, every board gets a picture rendered at the end — and I *look* at it. That's the real lesson here. Automation gets you ninety-five percent of the way. The last five percent is still you, looking at the thing with your own eyes.

---

## 10 · CLOSE — ~9:45

**[SCREEN: the grid of 12 boards again.]**

**VO:** So — twelve boards, one command. Scripts do the boring, mechanical ninety-five percent. The AI does the one bit that needs judgement: reading the docs and writing the notes. And a set of guardrails makes sure it can't hurt itself.

**TO CAMERA:** The lesson I actually want you to take away isn't "use AI." It's the opposite. The clever part was working out where *not* to. Even the AI knew that before I did.

**[SCREEN: repo link / atomic14 lower-third.]**

**TO CAMERA:** Everything's on GitHub, link below. And there's a whole other video in *how* the AI fills in that one file from the website — tell me in the comments if you want that one. Cheers.

**[END CARD.]**

---

## Shot list (film while it's fresh)

- The `make.py` time-lapse — the money shot. Film it clean.
- The LED safety hard-error firing live (beat 7).
- USB diff-pair vs single-ended fallback, two boards side by side (beat 8).
- The "green check that lied" — passing ERC next to the render with unconnected USB pins (beat 9).
- One `board.yaml` on screen — the only hand-authored file (beats 6).
- Two mirrored baseboards, reset/boot buttons swapping sides (beat 5).

## Accuracy notes (don't contradict the code on camera)

- **Baseboard mirror (beat 5)** = *physical layout*. The EN (reset) and BOOT pins
  swap sides as a pair between module families; the generator keys the choice off
  the EN pin's edge (`build_board.py: baseline_dir`) and picks `baseline-left-en`
  or `baseline-right-en`. No GPIO numbers here.
- **Boot pin (beat 6)** = *logical*. The `board.yaml` `boot` field — which GPIO
  the boot button pulls low for programming-vs-flash. GPIO0 on Xtensa (S2/S3),
  GPIO9 on most RISC-V (C3/C6/H2), GPIO28 on C5. This does NOT affect baseboard
  selection.
- The diff-pair fallback is real: routing defaults to diff-pair with a
  single-ended fallback (`route_all.py`, `--no-diff` forces single-ended).

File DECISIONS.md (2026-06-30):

# ESP Dev-Board Generator — Decisions & Process

A record of what we're building, the decisions made, the rationale, and how to
re-run the process. Read this first if you're picking the project back up.

## Mission

Create canonical *basic dev boards* for the Espressif module range — one
reference schematic per module. We add an Espressif module symbol plus
break-out pin headers (GPIO + power + GND) to a pre-built skeleton schematic,
and wire everything using **net labels** (no manual routing).

### Module selection criteria (user decision)

Only modules with **a PCB antenna AND native USB** (USB-OTG or USB-Serial-JTAG).
This excludes the classic ESP32 and ESP8266 (UART only) and ESP32-C2/ESP8684
(no native USB). IPEX/U.FL antenna variants are excluded.

Target set (all confirmed present in the installed symbol library):

| SoC | Modules | USB |
|-----|---|-----|
| ESP32-S2 | S2-MINI-1, S2-WROOM, S2-WROVER | USB-OTG |
| ESP32-S3 | S3-MINI-1, S3-WROOM-1, S3-WROOM-2¹ | OTG + Serial/JTAG |
| ESP32-C3 | C3-MINI-1, C3-WROOM-02 | Serial/JTAG |
| ESP32-C5 | C5-WROOM-1² | Serial/JTAG |
| ESP32-C6 | C6-WROOM-1, C6-MINI-1/U³ | Serial/JTAG |
| ESP32-H2 | H2-MINI-1 | Serial/JTAG |

¹ WROOM-2 uses octal flash/PSRAM → fewer free GPIO (do-not-break-out pins).
² C5-WROOM-1U is the IPEX variant — excluded.
³ One symbol "ESP32-C6-MINI-1/U" covers both PCB and IPEX variants.
ESP32-C61 matches the criteria but has **no symbol in the library yet** — deferred.

## Data sources

- **Module reference / specs**: https://www.atomic14.com/esp32/llms.txt (and the
  per-module/SoC pages it links). Used for editorial decisions (strapping pins,
  USB mapping confirmation, do-not-break-out pins).
- **Symbols / footprints / 3D**: Espressif KiCad libraries
  (https://github.com/espressif/kicad-libraries), installed via KiCad's Plugin &
  Content Manager. Appears as the **`PCM_Espressif`** library; placed symbols use
  `lib_id` `PCM_Espressif:<module-name>`.

## Toolchain decisions

| Concern | Choice | Why |
|---|---|-----|
| Python | **`uv`** (user requirement) | `uv init --bare`; `uv run python ...`. |
| Schematic editing | **`kicad-skip` 0.2.5** (`from skip import Schematic`) | Round-trip-safe on KiCad 10 — **proven**: load→write gave a pixel-identical PDF render and a byte-identical ERC report. It preserves unrecognised tokens (only whitespace changes). Emits harmless "can't parsy" warnings on load. |
| Validation | **`kicad-cli`** (ships with KiCad 10.0.3) | Native v10. NOT on PATH — lives at `/Applications/KiCad/KiCad.app/Contents/MacOS/kicad-cli`. |
| Symbol-lib parsing | **`sexpdata`** (kicad-skip dep) | Deterministic read of `Espressif.kicad_sym`. |

Rejected: `kiutils` for *writing* (targets ≈KiCad 7, rewrites whole file from a
strict model → risks dropping v10 tokens); the IPC API `kipy` (needs a running
KiCad, schematic support immature); `pcbnew` Python (PCB only).

## Validation philosophy (user decision: "validate via screenshots")

Two gates, both run by `scripts/lib/validate.py`:

1. **ERC delta vs the baseline.** The skeleton already has ~58 ERC violations by
   design (unconnected labels, undriven power, an `easyeda2kicad` lib not in the
   global table). So the bar is NOT "zero violations" — it's **"resolve some
   baseline violations and introduce no new ERRORS."** The gate is
   **error-severity only**: new *warnings* are acceptable and sometimes
   unavoidable. Concretely, connecting `GPIO0` to the boot button always adds one
   `pin_to_pin` warning, because the EasyEDA button symbol declares `Unspecified`
   pin types — that is a *correct* connection, not a defect. (An earlier,
   stricter "no new violations of any kind" gate sent an agent into an infinite
   loop chasing an impossible exit 0; `validate.py` now fails only on new
   errors and merely reports new warnings.)
2. **PDF render screenshot.** `kicad-cli sch export pdf` → the PDF is read back
   and visually inspected (the Read tool rasterises PDF pages).

## Repository structure

```
kicad_automation/
├── DECISIONS.md            # this file
├── README.md               # quick-start + script reference
├── docs/AGENT_END_TO_END.md  # agent spec: curate every board.yaml, then pilot-verify
├── library.json            # GENERATED by resolve_library.py — machine paths
├── pyproject.toml / .venv  # uv project
├── baseline-left-en/       # skeleton KiCad project — EN button on the left (input, do not edit)
├── baseline-right-en/      # skeleton mirrored — EN on the right; generator auto-picks per module
│   └── baseline.kicad_sch  # blocks + net labels: D+, D-, EN, BOOT, BUILTIN_LED, +3V3, +5V, GND
├── scripts/                # orchestrators (run these)
│   ├── make.py             # THE command: clean -> build_all -> route_all (-> render)
│   ├── resolve_library.py  # find PCM_Espressif + kicad-cli -> library.json
│   ├── build_all.py        # build + ERC-validate every curated module
│   ├── route_all.py        # autoroute + DRC every generated board
│   ├── render_boards.py    # 3D montages -> build/
│   ├── clean.py            # remove generated output
│   └── lib/                # per-module primitives, called by the orchestrators
│       ├── extract_pinout.py   # Espressif.kicad_sym -> modules/<m>/pinout.json
│       ├── footprint_edges.py  # footprint pad geometry -> physical edge per pin
│       ├── build_board.py      # THE generator: baseline + module + headers + labels -> .kicad_sch
│       ├── place_pcb.py        # clone baseline PCB, place module + headers, assign nets
│       ├── route_board.py      # autoroute one board via KiCadRoutingTools (sibling repo)
│       ├── fill_zones.py / gnd_finish.py / gnd_prestitch.py / hole_keepouts.py / via_repair.py  # PCB finishing
│       ├── validate.py         # ERC delta vs baseline + PDF render
│       └── fab_export.py       # Gerbers + Excellon drill -> out/<m>/<m>-fab.zip
├── modules/<module>/       # CURATED SOURCE only (committed)
│   ├── pinout.json         # AUTO — ground truth from the symbol, never hand-edited
│   └── board.yaml          # CURATED — the only hand-authored file (schema below)
├── out/<module>/           # GENERATED board — git-ignored, disposable (rm -rf out)
│   ├── <module>.kicad_sch/.kicad_pcb/.kicad_pro  # the generated, routed board
│   ├── fp-lib-table + *.pretty/ + asset dirs     # copied from baseline
│   ├── route_debug/        # per-stage routing snapshots for inspection
│   └── fab/ + <module>-fab.zip   # Gerbers + Excellon drill; .zip is fab-ready
└── build/<board>/          # validation artifacts (erc.json, *.pdf) — disposable
```

Decision: **source and output live in separate trees** — `modules/<M>/` holds
only the curated source (`board.yaml` + cached `pinout.json`), everything
generated goes under `out/<M>/`. So cleaning is `rm -rf out build` with no
name-matching heuristic, and the source tree stays pristine and reviewable.
(Earlier this was one folder per module; mixing generated files with the source
made a clean rebuild fragile.) Data is layered — auto-extracted truth
(`pinout.json`) vs human/curated decisions (`board.yaml`).

## Board-generation approach (user decision)

**Approach A — a deterministic script** builds each board by cloning the
baseline and injecting the module symbol, headers, and net labels from
`board.yaml`. Chosen over an LLM-per-board approach to honour the
"concrete repeatable scripts over burning tokens" principle. The
curated `board.yaml` removes all judgement, leaving pure mechanical placement.
*(An end-to-end agent run was used to discover the mechanics — see below.)*

### Header layout: perimeter-walk split (user decision)

Two break-out headers, laid out as a dev board (one each side of the module).
Allocation is driven by the module's **physical** layout, NOT the schematic
symbol's left/right sides (those are a drawing convention — almost every symbol
is right-heavy). Physical edges come from the **footprint** pad geometry
(`scripts/lib/footprint_edges.py`); pad numbers match symbol pin numbers.

Finding from surveying all 12 modules: form factor does **not** track the
WROOM/MINI naming, and **10 of 12 are 3-edge** (usable pins on left + bottom +
right; the top edge is 100% GND). Only C3-WROOM-02 and C6-WROOM-1 are 2-edge.

Policy: assign each break-out pin to the header on its **physical side** —
**left-edge pins → left header, right-edge pins → right header, bottom-edge pins
to whichever side of the module's horizontal centre they sit on** — ordered along
the perimeter walk (left edge top→bottom, bottom left→right, right edge
bottom→top) so header pins line up with the module pads without crossing. The
shorter header is then **padded with GND pins** so both headers are the same
length (a symmetric board). Degenerates to plain left/right for 2-edge modules.

(An earlier version cut the perimeter ring at the *count* midpoint; when the two
edges had unequal pin counts that pushed a right-edge pin into the left header,
forcing a cross-board route — hence the switch to physical-side assignment.)

Header construction rules (in `build_board.py`):
- **Spread the headers well clear** of the module body and its pin labels
  (`HEADER_OFFSET` from the module centre to each header).
- Conventional dev-board column: **positive rail (`+3V3` left / `+5V` right) at
  the TOP pointing up; GPIO in the middle; `GND` at the BOTTOM pointing down.**
  (KiCad's `power:GND` symbol has its pin at the top and graphic pointing down
  at rot 0; `+3V3`/`+5V` point up at rot 0 — both placed at rot 0.)
- GPIO labels point **outward** (away from the module).
- Excluded pins (`do_not_break_out`) and any other deliberately-unconnected
  signal pin get an explicit **no-connect flag** (else ERC errors).

### Auto-derived vs curated wiring

Most wiring is **auto-derived** from `pinout.json` + footprint, by pin name:
`3V3`→`+3V3`, `GND`→`GND`, `EN`/`CHIP_PU`→`EN`, `GPIO0`→`GPIO0`,
`*USB_D+`→`D+`, `*USB_D-`→`D-`. Each broken-out signal's net label is its
**primary name** (first `/`-separated token) — necessary because some usable
GPIO are function-named (`MTMS`, `U0TXD`, `ADC2_CH6`), not `GPIOxx`.

**Curated, per module, in `board.yaml`** (user decision — explicit, not
name-guessed): the **do-not-break-out** list, chiefly internal flash/PSRAM pins
(`SPIIO6/7`, `SPIDQS`, `SPI_CS1`, …), plus any per-module net overrides.

### Proposed `board.yaml` schema

```yaml
module: ESP32-C3-MINI-1
symbol: PCM_Espressif:ESP32-C3-MINI-1
do_not_break_out: []        # pin numbers or names — flash/PSRAM/reserved
overrides: {}               # pin (number|name) -> net label, to force a net
strapping: [2, 8, 9]        # GPIO numbers sampled at reset (atomic14/datasheet)
input_only: []              # GPIO numbers with no output driver
builtin_led: GPIO7          # on-board LED pin — safe GPIO pad nearest the LED
boot: GPIO9                 # download/boot strapping GPIO the BOOT button pulls low
notes: >                    # block scalar — capture special-role pins here
  Source: <atomic14 module URL>. Strapping/JTAG/UART/USB pins are still broken
  out per dev-board policy and documented here, not excluded.
```

`boot` is the SoC's download/boot strapping pin that the on-board BOOT button
pulls low: **GPIO0** on the Xtensa parts (ESP32 / -S2 / -S3), **GPIO9** on most
RISC-V parts (-C3 / -C6 / -H2), **GPIO28** on -C5 (from the datasheet / atomic14
page). It varies per module, so it can't be a fixed net name; the generator
aliases the skeleton's `BOOT` net onto this pin (same mechanism as the LED).

`strapping`/`input_only` are still broken out like any other pin; they exist so
the generator can route the **on-board LED** (`builtin_led`) to a pin that is
safe to drive — I/O-capable and not sampled at reset. `build_board.py`
`pick_builtin_led()` proposes the safe GPIO whose pad lands **physically closest
to the LED** on the laid-out PCB (shortest trace), and the build **hard-errors**
if `builtin_led` is a strapping /
input-only / non-broken-out pin. Mechanism: keep the pin's `GPIOxx` label and
add a second `BUILTIN_LED` global-label alias on it (the net carries both names;
KiCad canonicalises to `BUILTIN_LED`, matching the skeleton LED's PCB net). This
adds one expected `multiple_net_names` ERC warning.

### Two findings from the end-to-end run (to handle in the generator)

- **Power-symbol orientation**: place `+3V3`/`GND` symbols oriented from the
  pin's edge (top pin → symbol above pointing down, etc.) so they don't overlap
  the module body. (The experiment placed one `+3V3` on top of the symbol.)
- **NC "X" markers**: each module symbol declares many `no_connect`-type pins
  (e.g. C3-MINI-1 has 14, all on the left edge); KiCad always draws them with an
  X. These are inherent to the Espressif symbol, correct to leave unconnected,
  and not a defect.

## What the symbol gives us for free

Each pin in `pinout.json` has: number, name (alt-functions baked in, e.g.
`GPIO19/USB_D+`), electrical type, derived GPIO number, and position/side.
Notably the **USB D+/D- mapping is in the pin names** — not something we must
hand-curate. Still curated (not in the symbol): strapping pins, input-only pins,
and internal flash/PSRAM pins to leave unconnected. Strapping / input-only pins
are captured as the structured `strapping` / `input_only` lists in `board.yaml`
(consumed by the `builtin_led` picker + build-time safety gate), no longer only
as free-text in `notes`.

## Standard net labels (from the baseline skeleton)

The skeleton pre-defines these nets the module must connect to:
`+3V3` (power symbol), `GND` (power symbol + B.Cu copper pour), `+5V`, and global
labels `D+`, `D-`, `EN`, `BOOT`, `BUILTIN_LED`. `BOOT` and `BUILTIN_LED` are
aliased onto the module's boot-strapping GPIO and on-board-LED GPIO respectively,
per `board.yaml` (the GPIO differs by module — see the schema above).

## How to re-run from scratch

```bash
uv sync                                   # restore env (kicad-skip, sexpdata, pyyaml)
uv run python scripts/resolve_library.py  # -> library.json (set ESPRESSIF_3RDPARTY/KICAD_CLI if auto-detect fails)
uv run python scripts/make.py             # THE command: clean -> build_all -> route_all (--render for 3D)
# or stage by stage across all modules:
uv run python scripts/build_all.py        # build + ERC-validate every curated module
uv run python scripts/route_all.py        # autoroute + DRC every generated board
# single module:
uv run python scripts/lib/extract_pinout.py "ESP32-C3-MINI-1"
uv run python scripts/lib/build_board.py "ESP32-C3-MINI-1"
uv run python scripts/lib/validate.py out/ESP32-C3-MINI-1/ESP32-C3-MINI-1.kicad_sch
uv run python scripts/lib/route_board.py "ESP32-C3-MINI-1"
```

## Open items

- The generator script (Approach A): clone baseline → embed module lib_symbol →
  place module + two perimeter-split headers + power-symbols + net labels.
  (Mechanics proven by the end-to-end run; recover patterns from
  `out/ESP32-C3-MINI-1/ESP32-C3-MINI-1.kicad_sch`.)
- Curate each module's `board.yaml` (do-not-break-out flash/PSRAM pins).
- ESP32-C61: no library symbol yet.

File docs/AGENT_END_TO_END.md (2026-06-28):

# Agent Task: Curate board definitions, then pilot-verify the pipeline

The deterministic generator **and** router already exist — you RUN them, you do
not reinvent them. Your real job is the **judgement layer**: populate every
module's `board.yaml` (the per-module decisions the generator can't derive). Then
prove the recipe still works with **one end-to-end pilot** before the bulk
build + route, which is pure mechanics handled by our scripts.

Flow: **curate every `board.yaml` → pilot-verify one module → bulk build/route.**

## Read first
1. `DECISIONS.md` — the project spec (toolchain, header policy, validation, the
   `board.yaml` schema). Authoritative; follow it.
2. `baseline-left-en/baseline.kicad_sch` — the skeleton (for reference only).

## Hard rules
- Python only via `uv run python`. Env has kicad-skip, sexpdata, pyyaml.
- Use the scripts in `scripts/` — never hand-edit a schematic or PCB.
- `kicad-cli` is not on PATH; its path is in `library.json` (after Phase 0).
- Never modify `baseline-left-en/` or `baseline-right-en/` (the two skeleton
  variants; the generator auto-picks one per module by EN-pin side).

## Phase 0 — setup (once per machine)
- `uv run python scripts/resolve_library.py`   → writes `library.json`

## Phase 1 — curate every module's `board.yaml`  ← YOUR MAIN JOB

For **each** module dir under `modules/<M>/`:

1. Ensure pin data: `uv run python scripts/lib/extract_pinout.py "<M>"`
   → writes `modules/<M>/pinout.json`.
2. Fetch the module's atomic14 reference page
   (`https://www.atomic14.com/esp32/modules/<slug>/`, trailing slash) and use its
   **"do not use" / reserved / strapping / special-role** pin info.
3. Write `modules/<M>/board.yaml` per the DECISIONS.md schema:
   - **`do_not_break_out`** — pins that must NOT be exposed (internal flash/PSRAM,
     genuinely reserved). Strapping / JTAG / UART-console / USB pins are STILL
     broken out (normal for a dev board) — note them, don't exclude them. USB
     D+/D- are auto-routed by the generator and never broken out.
   - **`strapping` / `input_only`** — the SoC's GPIO numbers (drive LED safety).
   - **`builtin_led`** — the safe (I/O-capable, non-strapping) GPIO whose pad sits
     physically nearest the on-board LED. Get the suggestion from
     `build_board.pick_builtin_led()`; the build hard-errors on an unsafe choice.
   - **`boot`** — the download/boot strapping GPIO the BOOT button pulls low:
     GPIO0 on Xtensa (ESP32 / -S2 / -S3), GPIO9 on most RISC-V (-C3 / -C6 / -H2),
     GPIO28 on -C5. Confirm from the datasheet / atomic14 page.
   - **`notes`** — record the data source and any caveats.

   You are **only authoring definitions** here — not building or routing.

## Phase 2 — pilot-verify ONE module end-to-end

Pick a representative module (a dense MINI is the best stress test, e.g.
`ESP32-S3-MINI-1`) and run the full pipeline to confirm the recipe + your data:

- `uv run python scripts/lib/build_board.py "<M>"`
- `uv run python scripts/lib/validate.py out/<M>/<M>.kicad_sch`
  — then **Read the printed PDF** and check the module, power/USB/boot wiring, and
  both headers. Gate: **no new ERROR-severity violations** (script exits 0). New
  *warnings* are expected (e.g. the `multiple_net_names` from the LED/BOOT alias);
  **do NOT loop trying to drive warnings to zero.**
- `uv run python scripts/lib/route_board.py "<M>"` — expect
  **ALL NETS FULLY CONNECTED** and a clean DRC.

If a failure is a generator/router bug rather than a data issue, **report it** —
do not hack the output by hand.

## Phase 3 — bulk build + route (mechanical; scripts, not the agent)

Once the definitions are curated and the pilot is clean, every module is built and
routed by our scripts — no agent judgement involved:

- `uv run python scripts/make.py`   — clean → `build_all` (build + ERC) →
  `route_all` (autoroute + DRC); add `--render` for the 3D montages.

Run it yourself / let CI run it. Per-board details:
`build_all.py` (build + validate all), `route_all.py` (route + DRC all).

## Deliverables (final message)
1. Every module's `board.yaml`, with a one-line `do_not_break_out` justification
   per module (citing the atomic14 page).
2. Pilot result: the module verified, `validate.py` exit 0, route fully connected.
3. ERC delta summary for the pilot (resolved / new warnings).
4. **Process friction report**: anything in the recipe that was unclear, missing,
   or wrong first time — this is what we refine before trusting the bulk run. If
   it all worked cleanly, say so.

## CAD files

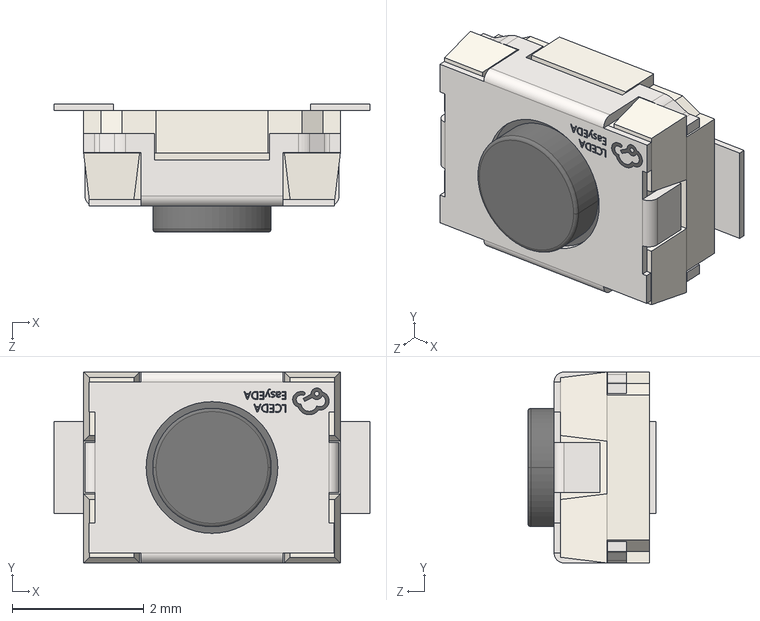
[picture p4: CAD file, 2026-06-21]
baseline-left-en/3d-models/SW-SMD_L3.9-W2.9-H2.0-LS4.8.step
4.80 x 2.90 x 1.95 mm

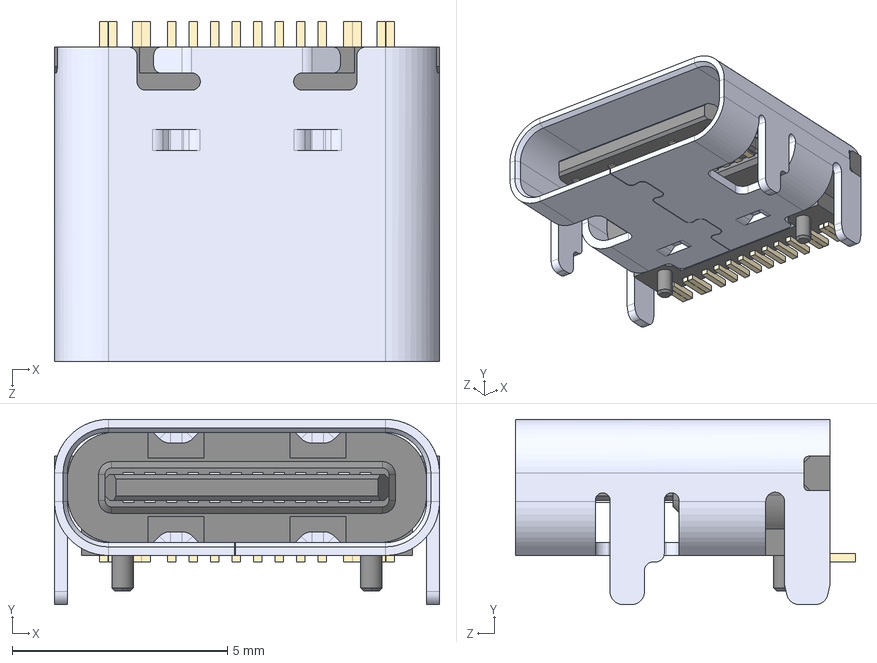
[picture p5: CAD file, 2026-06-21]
baseline-left-en/3d-models/TYPE-C-31-M-12.step
8.94 x 4.30 x 7.90 mm

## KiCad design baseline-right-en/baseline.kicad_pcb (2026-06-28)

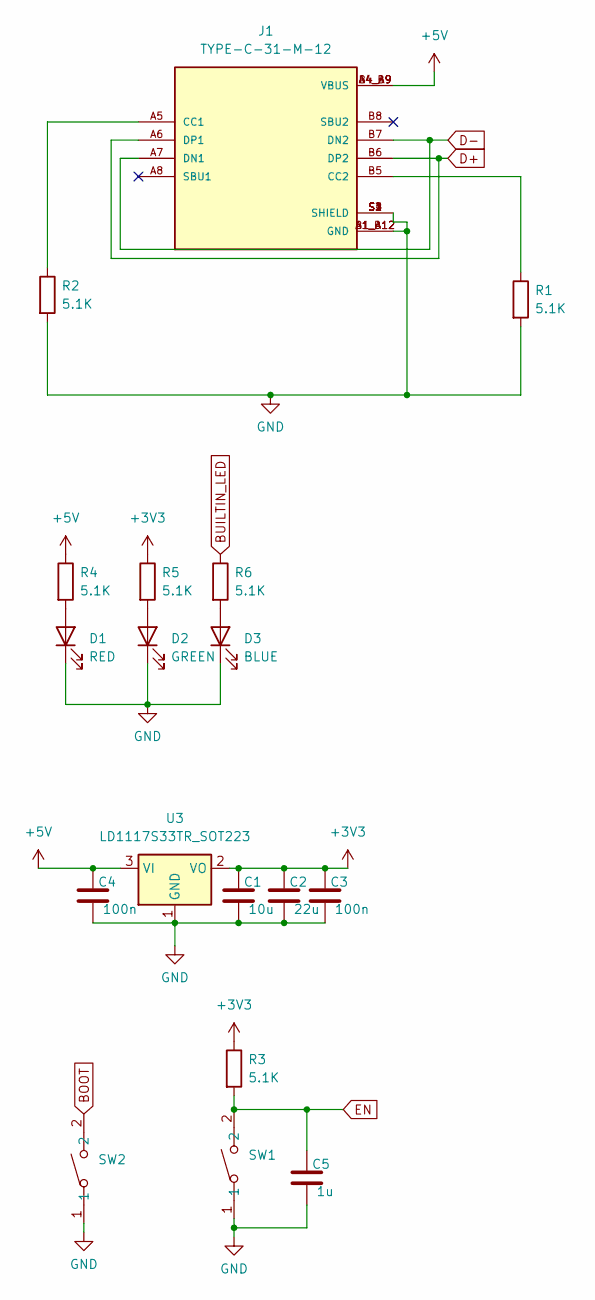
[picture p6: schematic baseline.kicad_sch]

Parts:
C1: 10u; C_0603_1608Metric
C2: 22u; C_0603_1608Metric
C3, C4: 100n; C_0603_1608Metric
C5: 1u; C_0603_1608Metric
D1: RED; LED_0603_1608Metric
D2: GREEN; LED_0603_1608Metric
D3: BLUE; LED_0603_1608Metric
J1: TYPE-C-31-M-12; HRO_TYPE-C-31-M-12; PARTREV 2020.12.08
R1, R2, R3, R4, R5, R6: 5.1K; R_0603_1608Metric
SW1, SW2: TS-1088-AR02016; SW-SMD_L3.9-W3.0-P4.45; LCSC Part C720477
U3: LD1117S33TR_SOT223; SOT-223-3_TabPin2

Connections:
+3V3: C1.1, C2.1, C3.1, R3.1, R5.1, U3.2 (VO)
+5V: C4.1, J1.A4_B9 (VBUS), J1.B4_A9 (VBUS), R4.1, U3.3 (VI)
BOOT: SW2.2
BUILTIN_LED: R6.1
D+: J1.A6 (DP1), J1.B6 (DP2)
D-: J1.A7 (DN1), J1.B7 (DN2)
EN: C5.1, R3.2, SW1.2
GND: C1.2, C2.2, C3.2, C4.2, C5.2, D1.1 (K), D2.1 (K), D3.1 (K), J1.A1_B12 (GND), J1.B1_A12 (GND), J1.S1 (SHIELD), J1.S2 (SHIELD), J1.S3 (SHIELD), J1.S4 (SHIELD), R1.2, R2.2, SW1.1, SW2.1, U3.1 (GND)
unnamed: D1.2 (A), R4.2
unnamed: D2.2 (A), R5.2
unnamed: D3.2 (A), R6.2
unnamed: J1.A5 (CC1), R2.1
unnamed: J1.B5 (CC2), R1.1

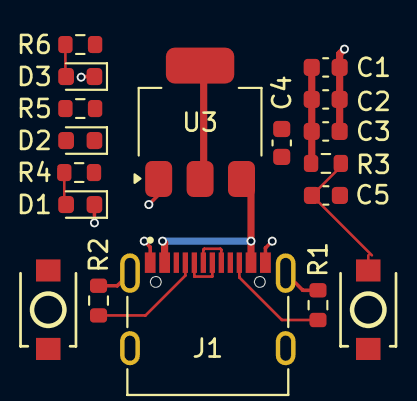
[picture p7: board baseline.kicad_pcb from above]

Board: 2 copper layers, 18 parts (0 on the bottom side), 11 nets.

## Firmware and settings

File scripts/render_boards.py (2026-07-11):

#!/usr/bin/env python3
"""Render 3D views of every generated board into 6x2 montages.

Produces six montages in build/ (+ the per-board build/<MODULE>/render_*.png
they're stitched from):
  montage_top.png       top, with components (the assembled board)
  montage_top_bare.png  top, NO components — the bare PCB artwork (copper/silk,
                        incl. the under-module silk marker), via a render of a
                        model-stripped copy of the board
  montage_bottom.png    bottom, with components
  montage_*_scale.png   the same three views TO SCALE: normally each render
                        auto-fits its board to the frame (losing relative
                        size), so the *_scale set re-renders with each board's
                        zoom cut by its true size vs the biggest board —
                        kicad-cli's --zoom is linear, so equal mm-per-pixel
                        across tiles. Labels carry the board's WxH mm.
  montage_hero.png      a perspective three-quarter "product shot" per board
                        (floor + shadows, HERO_ROTATE angle), stitched 4x3.
                        The per-board originals are build/<M>/render_hero.png.

Uses kicad-cli (path from library.json) for the 3D renders and ImageMagick
(`magick`) for the montage. The pin-header STEP models live next to KiCad's
bundled footprints, so KICAD10_3DMODEL_DIR is pointed there for the render.

Renders out/<M>/<M>.kicad_pcb (routing writes back in place, so this is the
routed board once it's been routed). Note: the GND copper pour is unfilled in
headless renders (it fills when opened in KiCad), so the montage shows the
tracks/vias but not the GND fill.

Usage:
  render_boards.py             # every board -> three montages
"""
from __future__ import annotations
import argparse
import json
import os
import shutil
import subprocess
import sys
from pathlib import Path

import sexpdata
from sexpdata import Symbol

REPO = Path(__file__).resolve().parent.parent
BUILD = REPO / "build"
TILE = "6x2"  # 12 boards -> 6 columns x 2 rows
RENDER_W, RENDER_H = 600, 850  # per-board render frame (px)
BASE_ZOOM = 0.8                # zoom of the auto-fit views (and the biggest board)

# Hero shot: perspective three-quarter view with floor shadows. The angle was
# picked by eye — tilted back and turned so the module, buttons, USB-C and the
# under-board header pins all read clearly.
HERO_W, HERO_H = 1400, 1000
HERO_ROTATE = "-45,0,25"
HERO_ZOOM = 0.8   # 0.9 clipped the front (USB) edge of the board
HERO_TILE = "4x3"              # landscape tiles pack better 4 wide

# Montages to produce: (side, with_components, name). The bare-board view strips
# the 3D component models so the PCB artwork (copper/silk, incl. the under-module
# silk marker) is visible — what the board looks like before assembly.
VIEWS = [
    ("top", True, "top"),
    ("top", False, "top_bare"),
    ("bottom", True, "bottom"),
]

# Common font locations (macOS / Linux) for the montage labels; labels are
# dropped if none is found rather than failing the whole render.
FONT_CANDIDATES = [
    "/System/Library/Fonts/Supplemental/Arial.ttf",
    "/Library/Fonts/Arial.ttf",
    "/System/Library/Fonts/Helvetica.ttc",
    "/usr/share/fonts/truetype/dejavu/DejaVuSans.ttf",
    "/usr/share/fonts/truetype/liberation/LiberationSans-Regular.ttf",
]


def find_font():
    return next((f for f in FONT_CANDIDATES if Path(f).exists()), None)


def boards():
    """(module_name, pcb_path) for every module with a generated PCB."""
    out = []
    for d in sorted((REPO / "out").glob("*/")):
        pcb = d / f"{d.name}.kicad_pcb"
        if pcb.exists():
            out.append((d.name, pcb))
    return out


def board_dims(pcb_path: Path) -> tuple[float, float]:
    """(width, height) in mm of the board's Edge.Cuts gr_rect outline."""
    tree = sexpdata.loads(pcb_path.read_text())

    def sub(node, tag):
        return next((c for c in node if isinstance(c, list) and c
                     and isinstance(c[0], Symbol) and c[0].value() == tag), None)

    for node in tree:
        if not (isinstance(node, list) and node and isinstance(node[0], Symbol)
                and node[0].value() == "gr_rect"):
            continue
        layer = sub(node, "layer")
        if not layer or "Edge.Cuts" not in str(layer[1]):
            continue
        s, e = sub(node, "start"), sub(node, "end")
        return abs(float(e[1]) - float(s[1])), abs(float(e[2]) - float(s[2]))
    raise RuntimeError(f"no Edge.Cuts gr_rect outline in {pcb_path}")


def scale_zooms(dims: dict) -> dict[str, float]:
    """Per-board zoom that puts every render at the same mm-per-pixel.

    kicad-cli auto-fits each board to the frame, so at a fixed zoom the
    px-per-mm is proportional to min(W/w, H/h) — undo that ratio so the
    biggest board keeps BASE_ZOOM and the rest shrink to true relative size."""
    fit = {name: min(RENDER_W / w, RENDER_H / h) for name, (w, h) in dims.items()}
    biggest = min(fit.values())
    return {name: BASE_ZOOM * biggest / f for name, f in fit.items()}


def strip_models(pcb_path: Path, dest: Path) -> Path:
    """Write a copy of the board with every (model ...) node removed, so a render
    of it shows the bare PCB (copper/silk/mask/pads) with no 3D component bodies.
    Round-tripping through sexpdata is fine here — it's a throwaway render copy."""
    tree = sexpdata.loads(pcb_path.read_text())

    def strip(node):
        if not isinstance(node, list):
            return node
        return [strip(c) for c in node
                if not (isinstance(c, list) and c and isinstance(c[0], Symbol)
                        and c[0].value() == "model")]

    dest.write_text(sexpdata.dumps(strip(tree)))
    return dest


def render(cli, model_dir, pcb, side, out, zoom=BASE_ZOOM):
    env = {**os.environ, "KICAD10_3DMODEL_DIR": str(model_dir)}
    subprocess.run(
        [cli, "pcb", "render", "--side", side, "--background", "opaque",
         "--quality", "high", "--zoom", f"{zoom:.4f}",
         "-w", str(RENDER_W), "-h", str(RENDER_H),
         "-o", str(out), str(pcb)],
        check=True, env=env, capture_output=True)


def render_hero(cli, model_dir, pcb, out):
    env = {**os.environ, "KICAD10_3DMODEL_DIR": str(model_dir)}
    subprocess.run(
        [cli, "pcb", "render", "--background", "opaque", "--quality", "high",
         "--floor", "--perspective", "--rotate", HERO_ROTATE,
         "--zoom", str(HERO_ZOOM), "-w", str(HERO_W), "-h", str(HERO_H),
         "-o", str(out), str(pcb)],
        check=True, env=env, capture_output=True)


def montage(images, labels, out, font, tile=TILE, geometry="300x430+6+10"):
    # ImageMagick 7 is `magick montage`; IM6 (e.g. Ubuntu 24.04) only has the
    # standalone `montage` binary.
    args = ["magick", "montage"] if shutil.which("magick") else ["montage"]
    for img, lab in zip(images, labels):
        if font:
            args += ["-label", lab]
        args.append(str(img))
    if font:
        args += ["-font", font]
    args += ["-tile", tile, "-geometry", geometry,
             "-background", "white", "-fill", "black", "-pointsize", "14",
             str(out)]
    subprocess.run(args, check=True)


def main():
    ap = argparse.ArgumentParser()
    ap.parse_args()

    lib_path = REPO / "library.json"
    if not lib_path.exists():
        print("ERROR: library.json missing — run resolve_library.py first.", file=sys.stderr)
        return 1
    if not (shutil.which("magick") or shutil.which("montage")):
        print("ERROR: ImageMagick (`magick` or `montage`) not found on PATH.",
              file=sys.stderr)
        return 1
    lib = json.loads(lib_path.read_text())
    cli = lib["kicad_cli"]
    # bundled 3D models sit beside the bundled footprints: <SharedSupport>/3dmodels
    model_dir = Path(lib["kicad_symbols_dir"]).parent / "3dmodels"

    bds = boards()
    if not bds:
        print("No generated boards found — run build_all.py first.", file=sys.stderr)
        return 1
    dims = {name: board_dims(pcb) for name, pcb in bds}
    zooms = scale_zooms(dims)
    print(f"Rendering {len(bds)} boards")

    font = find_font()
    for side, with_comps, tag in VIEWS:
        imgs, scale_imgs, labels, scale_labels = [], [], [], []
        for name, pcb in bds:
            src, tmp = pcb, None
            if not with_comps:
                tmp = pcb.parent / f"{name}.nocomp.kicad_pcb"
                src = strip_models(pcb, tmp)
            out = BUILD / name / f"render_{tag}.png"
            out_scale = BUILD / name / f"render_{tag}_scale.png"
            out.parent.mkdir(parents=True, exist_ok=True)
            print(f"  render {tag:8} {name}")
            render(cli, model_dir, src, side, out)
            render(cli, model_dir, src, side, out_scale, zooms[name])
            if tmp:
                tmp.unlink()
            imgs.append(out)
            scale_imgs.append(out_scale)
            labels.append(name)
            w, h = dims[name]
            scale_labels.append(f"{name}  {w:.0f}x{h:.0f}mm")
        for images, labs, suffix in ((imgs, labels, ""),
                                     (scale_imgs, scale_labels, "_scale")):
            dest = BUILD / f"montage_{tag}{suffix}.png"
            montage(images, labs, dest, font)
            print(f"Wrote {dest}  ({len(images)} boards, {TILE})")

    hero_imgs, hero_labels = [], []
    for name, pcb in bds:
        out = BUILD / name / "render_hero.png"
        print(f"  render hero     {name}")
        render_hero(cli, model_dir, pcb, out)
        hero_imgs.append(out)
        hero_labels.append(name)
    dest = BUILD / "montage_hero.png"
    montage(hero_imgs, hero_labels, dest, font,
            tile=HERO_TILE, geometry="420x300+6+10")
    print(f"Wrote {dest}  ({len(hero_imgs)} boards, {HERO_TILE})")
    return 0


if __name__ == "__main__":
    raise SystemExit(main())

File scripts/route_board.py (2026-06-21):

#!/usr/bin/env python3
"""Auto-route a generated board with KiCadRoutingTools (external sibling repo).

2-layer boards: module / USB-C / passives on F.Cu, break-out headers on B.Cu,
so most nets cross layers (a via per net). Routed in incremental passes:

  diff pair (opt-in)  D+/D- as a coupled pair. Off by default (--diff): the run
                      is ~2mm — too short to benefit — and a coupled pair shorts
                      in the 0.5mm-pitch USB-C escape.
  USB-C fine neck     D+/D-/CC at 0.15mm; the board's 0.2mm rule can't escape the
                      0.5mm-pitch USB-C pads. A USB net class + baseline.kicad_dru
                      custom rule keep that DRC-legal (rest of the board is 0.2mm).
  signals             everything else at the board rule (0.2mm track / 0.2mm
                      clearance, 0.5/0.3 vias), free to use either layer.
  GND plane pour      GND poured on F.Cu + B.Cu, vias stitched to its pads.

Writes modules/<M>/<M>_routed.kicad_pcb (plus the .kicad_pro/.kicad_dru sidecars
so DRC sees the net classes + USB rule) and prints a connectivity report.

Requires KiCadRoutingTools as a sibling dir (../KiCadRoutingTools), or --tool /
$KICAD_ROUTING_TOOLS, with its Rust router built (python build_router.py) and
numpy/scipy/shapely available to `python3`.

Usage:
  route_board.py "ESP32-C3-MINI-1" [--tool DIR] [--diff] [--no-gnd-pour]
"""
from __future__ import annotations
import argparse
import json
import os
import re
import shutil
import subprocess
import sys
from pathlib import Path

REPO = Path(__file__).resolve().parent.parent

# Board design rules (from baseline.kicad_pro): the routing defaults.
TRACK_WIDTH = 0.2
CLEARANCE = 0.2
VIA_SIZE = 0.5
VIA_DRILL = 0.3
BOARD_EDGE_CLEARANCE = 0.5  # = baseline min_copper_edge_clearance
HOLE_TO_HOLE = 0.25         # = baseline min_hole_to_hole
LAYERS = ["F.Cu", "B.Cu"]
# Equal layer costs: the router defaults to penalising B.Cu 3x (it assumes a
# bottom ground plane), which crowds signals onto the top and fails the dense
# MINI boards. Our headers are on B.Cu, so both layers are first-class.
LAYER_COSTS = ["1.0", "1.0"]
# Finer neck for escaping the 0.5mm-pitch USB-C pads (below the board's 0.2mm
# rule — a local exception the USB-C footprint forces; flagged in the report).
USB_TRACK_WIDTH = 0.15
USB_CLEARANCE = 0.15
USB_GRID_STEP = 0.05
DIFF_PAIR_GAP = 0.15  # P-to-N gap for the USB D+/D- pair
POWER_WIDTH = 0.4     # +3V3/+5V routed wider than signals, and routed FIRST so
                      # they claim clean paths (incl. the empty bottom) before
                      # the GPIO fan-out fills it. Routing power first lets it use
                      # the bottom freely at the default via cost — lowering the
                      # via cost only added vias to the power path without helping.
POWER_NETS = ["+3V3", "+5V"]
GND_VIA_PAD_CLEARANCE = 0.1  # place GND stitching vias BESIDE pads (not in them),
                             # this far from the pad edge; via-in-pad is normally
                             # discouraged on SMD pads
# USB-C / CC nets that need the fine-neck pass (constant across boards — all
# share the baseline J1 USB-C connector).
USB_NETS = ["D+", "D-", "Net-(J1-CC1)", "Net-(J1-CC2)"]


def find_tool(explicit: str | None) -> Path:
    for cand in [explicit, os.environ.get("KICAD_ROUTING_TOOLS"),
                 REPO.parent / "KiCadRoutingTools"]:
        if cand and (Path(cand) / "route.py").exists():
            return Path(cand)
    raise SystemExit("KiCadRoutingTools not found — pass --tool DIR or set "
                     "$KICAD_ROUTING_TOOLS (sibling ../KiCadRoutingTools expected).")


def kicad_python() -> str:
    """KiCad's bundled python (has pcbnew, for zone filling). Derived from the
    kicad-cli path in library.json; falls back to `python3` (Linux distros put
    pcbnew in the system python)."""
    lib = REPO / "library.json"
    if lib.exists():
        cli = Path(json.loads(lib.read_text())["kicad_cli"])
        cand = cli.parents[1] / "Frameworks/Python.framework/Versions/Current/bin/python3"
        if cand.exists():
            return str(cand)
    return "python3"


def board_nets(pcb: Path) -> set[str]:
    """Every net name referenced on a pad in the board."""
    text = pcb.read_text()
    return set(re.findall(r'\(net "([^"]+)"\)', text))


def run_pass(tool: Path, label: str, inp: Path, out: Path, nets: list[str],
             track: float, clearance: float, grid_step: float | None,
             via_cost: int | None = None) -> dict:
    """Run one route.py pass over `nets`; return its JSON summary."""
    cmd = ["python3", "route.py", str(inp), str(out), *nets,
           "--layers", *LAYERS, "--layer-costs", *LAYER_COSTS,
           "--ordering", "mps", "--max-ripup", "8",
           "--track-width", str(track), "--clearance", str(clearance),
           "--via-size", str(VIA_SIZE), "--via-drill", str(VIA_DRILL),
           "--board-edge-clearance", str(BOARD_EDGE_CLEARANCE),
           "--hole-to-hole-clearance", str(HOLE_TO_HOLE)]
    if via_cost is not None:
        cmd += ["--via-cost", str(via_cost)]
    if grid_step:
        cmd += ["--grid-step", str(grid_step)]
    print(f"\n=== pass: {label} ({len(nets)} nets, {track}mm/{clearance}mm) ===")
    proc = subprocess.run(cmd, cwd=tool, capture_output=True, text=True)
    summary = {}
    for line in proc.stdout.splitlines():
        if line.startswith("JSON_SUMMARY:"):
            summary = json.loads(line[len("JSON_SUMMARY:"):])
    if proc.returncode != 0 and not summary:
        sys.stderr.write(proc.stdout[-2000:] + proc.stderr[-1000:])
        raise SystemExit(f"route.py failed in pass '{label}'")
    se = f"{summary.get('successful', '?')}/{summary.get('successful', 0) + summary.get('failed', 0)}"
    print(f"  single-ended {se} routed, {summary.get('total_vias', '?')} vias"
          + (f", FAILED {summary['failed_single']}" if summary.get("failed_single") else ""))
    return summary
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

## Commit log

2026-06-21 ESP dev-board generator: schematic + deterministic PCB layout
    Generates a canonical dev board for each of the 12 PCB-antenna + native-USB
    Espressif modules from a shared baseline skeleton:
    - scripts/extract_pinout.py symbol -> pinout.json (GPIO number taken from the
    GPIOxx token, not a loose regex that mis-read SPIIO4 as GPIO4)
    - scripts/build_board.py schematic via net labels + perimeter-split headers
    - scripts/place_pcb.py deterministic PCB layout: places module + headers,
    assigns nets, draws the board outline; headers are bottom-mounted (pins down)
    and the right header is flipped so both route 1:1 with no crossings
    - scripts/footprint_edges/validate/build_all supportin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
    [SW-SMD_L3.9-W2.9-H2.0-LS4.8.step, TYPE-C-31-M-12.step, baseline.kicad_pcb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]
2026-06-21 Add autorouting pipeline (KiCadRoutingTools) + USB-C footprint/rule fixes
    Routes the generated boards with the external KiCadRoutingTools, tuned for
    these 2-layer boards (module/USB/passives on F.Cu, headers on B.Cu):
    - scripts/route_board.py per-board pipeline: D+/D- single-ended (--diff for a
    coupled pair), USB-C fine neck (0.15mm to escape the 0.5mm-pitch pads), power
    rails first @0.4mm (claim the empty bottom before GPIO fan-out fills it),
    signals @0.2mm, 0.15mm self-heal retry, then a GND copper-plane pour on both
    layers. Equal layer costs (the tool defaults to penalising B.Cu 3x) + MPS
    ordering. Writes <M>_routed.kicad_pcb + .kicad_pro/.kicad_dru sidecars.
    - scripts/route_a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
    [baseline.kicad_pcb]
2026-06-21 render_boards: prefer the routed board, add --unrouted
    The montage now renders <M>_routed.kicad_pcb when present (so it shows the
    routed result), falling back to the bare board; --unrouted forces the latter.
    Headless renders leave the GND pour unfilled, so the montage shows tracks/vias
    but not the GND fill (it fills when opened in KiCad).
2026-06-21 GND: pcbnew zone fill + island stitching; beside-pad stitching vias
    kicad-cli can't fill zones, but KiCad's bundled pcbnew can, so finish the GND
    pour with a pcbnew step after the route_planes pour:
    - scripts/gnd_finish.py fills the GND zones (ZONE_FILLER), stitches any F.Cu
    GND island down to the B.Cu pour with a via placed safely inside both pours
    (a clearance disk that can't short to other-net copper), and sets the zones
    to drop empty isolated islands on fill
    - route_board.py runs gnd_finish (via KiCad's bundled python, located from the
    kicad-cli path) after the pour; GND stitching vias are now placed BESIDE pads
    (--same-net-pad-clearance) instead of in-pad
    Result across all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
    [route_board.py]
2026-06-21 gnd_finish: drop empty islands on fill + safe orphan-via prune
    - Set GND zones to remove isolated islands on fill (good practice for a pour).
    - prune_orphan_vias: remove any GND via whose bottom end isn't in the B.Cu pour
    (it can't be stitching anything to main and only holds an orphan island
    alive). Geometric test, not the pcbnew connectivity API — an earlier
    cluster-based prune misread partial clusters and removed needed vias,
    disconnecting copper. Safe: every GND pad already reaches the pour, so none
    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
2026-06-22 ESP dev-board generator: on-board LED wiring + GPIO-safety curation + routing robustness
    Wire the skeleton's BUILTIN_LED net to a safe module GPIO on every board.
    board.yaml gains structured strapping/input_only lists + a builtin_led pin; the
    generator picks the safe (I/O-capable, non-strapping, broken-out) pad physically
    NEAREST the on-board LED on the laid-out PCB (shortest trace) and aliases
    BUILTIN_LED onto that pin's GPIOxx net. build_board hard-errors if builtin_led is
    a strapping / input-only / non-broken-out pin. All 12 boards now wire the LED and
    route fully connected + DRC-clean.
    - build_board.py: resolve_led_pin (build-time safety gate) + pick_builtin_led
    (nearest-pad heuristic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
    [baseline.kicad_pcb, baseline.kicad_sch]
2026-06-22 route_board: final GND mop-up pass to catch any unconnected GND
    After the GND plane pour + island stitch, if any GND pad is still unconnected,
    route it as a track to the nearest GND copper and re-fill the zone. Other nets
    stay frozen (no rip-up). No-op in the normal case (the pour connects everything);
    a safety net for residual stranded GND pads. All 12 boards remain fully
    connected + DRC-clean.
2026-06-25 Routing pipeline: per-module BOOT mapping, by-side header allocation, GND-plane + via fixes
    Build/schematic:
    - BOOT net mapped to each module's actual boot/strapping GPIO (board.yaml `boot:`),
    mirroring the builtin_led alias — was hard-wired to GPIO0, wrong on RISC-V parts.
    - breakout_split now allocates header pins BY PHYSICAL SIDE (left edge->left header,
    right edge->right, bottom by x) instead of a count midpoint, which dumped
    right-edge pins into the left header on unbalanced left/right-only modules
    (C5/C6-WROOM) so they routed across the board. Shorter header padded with GND.
    - Deterministic UUIDs (uuid5 over a counter) so rebuilds are byte-identical;
    random uuid4s reshuffle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
    [baseline.kicad_pcb, baseline.kicad_sch]
2026-06-25 almost working
    [SW-SMD_L3.9-W2.9-H2.0-LS4.8.step, TYPE-C-31-M-12.step, baseline.kicad_pcb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]
2026-06-25 route_board: equal layer costs (12/12 routes), keep-best recovery pass, doc refresh
    - LAYER_COSTS 1.0/1.0 (was 1.0/3.0): the 3x B.Cu penalty choked a 2-layer board
    onto F.Cu; using both layers equally lets every board route — 12/12 connected
    and DRC-clean.
    - Recovery pass: if the mps pass strands nets, retry ONCE from the same clean
    pre-route input with the stranded nets first (original ordering), kept only if
    it strictly improves — never worsens a passing board. Rip-up escalation was
    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
2026-06-25 Remove dead code: gnd_finish stitching, unused via_cost / LED-picker helpers
    - gnd_finish.py: drop the commented-out stitch/refill loop and the helpers only
    it referenced (gnd_netcode, merged_polys, disk_inside, add_via, prune_orphan_vias,
    stitch_pass + their constants/import). What runs is just fill + island removal.
    - route_board.run_pass: drop the never-passed `via_cost` parameter and its branch.
    - build_board.pick_builtin_led: remove — an LED-suggestion curation helper with no
    callers anywhere; and place_pcb.net_pad_global, which only it used.
    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
2026-06-25 Restore pick_builtin_led + net_pad_global — used by the board.yaml curation flow
    These aren't dead: the agent flow that authors board.yaml calls pick_builtin_led
    to suggest the on-board LED pin (and it uses place_pcb.net_pad_global). My earlier
    removal was wrong — the caller lives outside scripts/, so the repo grep missed it.
    Restored both verbatim from d8c709a. The gnd_finish stitching and run_pass via_cost
    removals stand (those were genuinely unreferenced).
2026-06-25 route_board: auto-fallback diff -> single-ended (every board tries diff first)
    Default routing now tries the coupled D+/D- diff pair, and if it leaves nets
    unrouted, re-routes single-ended and keeps whichever connects more — so every
    board gets a shot at diff routing without a board the pair strands losing out.
    --diff / --no-diff still force a single mode; no D+/D- pair is single-ended only.
    Replaces the per-module board.yaml `diff:` setting (and drops the diff:false
    entries on S2/S3-MINI — no longer needed: with equal layer costs they route on
    the diff attempt anyway, and the fallback covers any board that doesn't).
    12/12 boards connected and DRC-clean.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
2026-06-25 docs: refocus agent on curation + pilot; document boot field & baseline variants
    - AGENT_END_TO_END.md: rewritten as a phased flow — Phase 1 (the agent's job)
    curates EVERY module's board.yaml; Phase 2 pilot-verifies ONE module end-to-end
    (build + ERC + route); Phase 3 bulk build/route is pure mechanics via make.py /
    build_all + route_all, not the agent. Parametrised (no hardcoded module) and
    points at the current scripts.
    - board.yaml schema (DECISIONS.md + README.md): document the new `boot:` field
    (download/boot strapping GPIO — GPIO0 Xtensa / GPIO9 RISC-V / GPIO28 C5).
    - Replace stale single `baseline/` with the two EN-variant skeletons
    (baseline-left-en / baseline-right-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
2026-06-25 DECISIONS.md modernise + route_all: stop masking unconnected GND
    - DECISIONS.md: fix the directory tree (scripts now under scripts/ + scripts/lib;
    add make.py/route_all/render/clean, place_pcb/route_board/fill_zones/etc., the
    routed PCB + route_debug outputs); net labels GPIO0/GPIO21 -> BOOT/BUILTIN_LED
    with the per-module alias note; header split described as physical-side + GND
    padding (was the old count-midpoint); re-run section now includes make.py /
    route_all / route_board.
    - route_all.py: count unconnected_items as real DRC errors (was excluded as a
    benign GND zone-fill artifact). With the GND pour + fill there should be NONE;
    any unconnected item is a real defect, so sur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
    [route_all.py]
2026-06-25 gnd_finish: refill the GND plane, then delete orphan GND stubs (11/12 clean)
    The pre-route fill goes stale once route.py lays B.Cu tracks through the plane,
    so gnd_finish re-fills (kicad-cli can't). The correctly-carved fill then leaves
    the odd route_planes stitching via+track electrically isolated from the main pour
    — a real unconnected_items error (every GND PAD still reaches the pour, so the
    stub is dead copper). cleanup_orphans deletes any GND track/via not in the main
    GND cluster (pcbnew GetConnectedItems traverses the filled zone) — conservative:
    it can't remove a real pad, which is why it leaves C3-WROOM-02's genuinely
    unconnected GND header pad alone (a separate routing-coverage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
2026-06-26 place_pcb: top-align pin headers with the module (shorter break-out traces)
    Headers were bottom-aligned to the USB edge, so on a tall board with a short
    header the pins sat far below a top-mounted module — long diagonal break-out
    traces, F.Cu congestion, and a GND header pin getting boxed in (unconnected).
    Now each header's courtyard TOP aligns with the module body top, so its pins
    overlap the module's pin rows. A header LONGER than the module->USB span stays
    bottom-aligned to the USB and the board grows UP to fit it (minimum board height
    = header height) — preserving the long-header (MINI) layout exactly. The module
    placement is UNCHANGED (moving it shifts the antenna keepout onto the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
2026-06-27 0.4mm power nets
    [baseline.kicad_pcb]
2026-06-28 resolve_library/make: pin Espressif lib to the running KiCad version
    find_3rdparty now resolves the addon for the version of the running kicad-cli
    instead of silently picking the newest addon on disk, so it never mixes a
    library built for one KiCad version with another's binary. Fails loudly with
    PCM install steps when the addon is missing for the running version. make.py
    now validates that library.json's recorded paths still resolve (catches the
    stale-after-upgrade case) rather than only checking the file exists.
    [make.py, resolve_library.py]
2026-06-28 baseline: tweak BOOT/EN button footprint silkscreen + re-save boards
    [baseline.kicad_pcb]
2026-06-28 route: GND finishing pipeline + pre-route pad pre-stitch
    gnd_finish: refill the GND pour, stitch F.Cu/B.Cu islands with a via, drop
    orphan stubs. gnd_stragglers: route a real GND track to a cut-off pad a via
    can't bridge.
    New gnd_prestitch: before routing (B.Cu plane still whole) drop a clean via
    from each top-side GND pad to the plane so route.py flows signals around them.
    This fixes pads that otherwise strand on a carved-off F.Cu island with no
    DRC-clean repair spot left post-route (canonical case: ESP32-S3-MINI-1 U1.64,
    where the nearest GND copper is the exposed pad 7.6mm away and unroutable).
2026-06-28 restructure: generated boards -> out/, modules/ is source-only
    modules/<M>/ now holds only the curated source (board.yaml + cached pinout.json);
    all generated boards go to out/<M>/, validation to build/<M>/. Cleaning is just
    rm -rf out build (clean.py) with no name-matching heuristic, and .gitignore drops
    its parallel list of generated patterns. build_board/route_board/route_all/
    build_all/render_boards updated to read source from modules/ and write to out/.
    Docs (CLAUDE.md, README, DECISIONS, AGENT_END_TO_END) updated to match.
2026-06-30 fab: export Gerbers + Excellon drill as a fab-ready zip per board
    New fab_export.py (one module) + fab_all.py (every board) produce
    out/<M>/<M>-fab.zip: the standard 2-layer Gerber set + Excellon drill, drill
    map and .gbrjob, flat-zipped for upload to a board house. Loose files are also
    kept in out/<M>/fab/. The Gerber export runs --check-zones so the GND copper
    pour is refilled and always present in the copper Gerbers (headless tools save
    empty fills — otherwise the board would ship with no ground plane). Gerbers and
    drill share an absolute origin.
    Wired into make.py as the opt-in --fab stage (and into --all): the pipeline is
    now clean -> build -> route -> render -> fab. Docs (CLAUDE.md,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
    [fab_all.py, make.py]
2026-06-30 place_pcb: add hidden silk order-number marker under the module
    build_board now drops an F-silk text (SILK_MARKER_TEXT, default "WayWayWay")
    centred in the clear band just above the module's bottom pin row — under the
    body so it's hidden once soldered, giving the board house a spot for its order
    number instead of it landing on visible silk. Placement uses KiCad's real
    rendered text bbox (height ~1.7x nominal, measured) and clearance-checks the box
    against every pad, shrinking the size to fit tight MINI modules; it never sits
    on exposed copper. Verified centred (x=160) and >=0.26mm clear on all 12 boards.
2026-06-30 render_boards: add a top, no-components montage (bare PCB artwork)
    Adds build/montage_top_bare.png alongside the existing top (with components) and
    bottom montages. The bare view renders a copy of each board with all (model ...)
    nodes stripped, so the 3D component bodies vanish and the PCB artwork is visible
    — copper, silk, and the under-module 'WayWayWay' marker that the assembled view
    hides. Temp model-stripped copies are cleaned up after each render.
2026-07-11 Back-silk board IDs, to-scale + hero renders, README gallery, CI releases
    - place_pcb: every board gets a vertical B-silk identifier centred on the
    back — module name + `git describe --tags --always --dirty` — auto-sized
    to the board height (drops the revision before the name if tight)
    - render_boards: to-scale montage set (equal mm-per-pixel via linear
    per-board zoom correction, labels carry WxH mm) + a perspective hero
    shot per board with floor shadows; IM6 `montage` fallback for CI
    - README: gallery (hero + to-scale front/back snapshots in docs/images/),
    CI/releases section
    - GitHub Actions: full pipeline on Ubuntu (KiCad 10 PPA + headless PCM
    addon install + xvfb), artifa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
    [render_boards.py]
2026-07-11 ci: fix KiCad PPA name (kicad-10.0-releases)
2026-07-11 ci: run resolve_library under xvfb (kicad-cli segfaults headless)
2026-07-11 ci: install kicad with recommended deps (segfaults without them)
2026-07-11 ci: build inside the official kicad/kicad:10.0-full docker image
    The Ubuntu PPA build of kicad-cli segfaults on GitHub runners even for
    plain 'version'; the official image is the supported headless path and
    bundles the stock libraries + 3D models.
2026-07-11 ci: temporary diagnostics for kicad-cli teardown segfault
2026-07-11 ci: seed KiCad global library tables (fixes PCM traversal segfault)
    kicad-cli 10 crashes in PCM_LIB_TRAVERSER at startup when the PCM addon
    dir exists but the global sym/fp lib tables were never created (fresh
    HOME, GUI never run). Replace the diagnostics with the fix + a canary.
2026-07-11 ci: install pinned+patched KiCadRoutingTools for the route stage
    The autorouter lives in a sibling repo; CI clones it at the pinned
    commit and applies the vendored local patch (--same-net-pad-clearance,
    required by route_board.py). Prebuilt Rust router comes from that
    project's releases; numpy/scipy/shapely via apt for system python3.
2026-07-11 ci: use atomic14/KiCadRoutingTools fork, build Rust router from source
    The local routing fixes now live on the fork's dev-board-fixes branch
    (pinned by commit) instead of a vendored patch file. The pinned
    Cargo.toml version (0.16.2) has no prebuilt release, so install rustup
    and build with --from-source — same as the local setup.
2026-07-11 docs: document the KiCadRoutingTools sibling prerequisite
2026-07-11 ci: upload boards artifact even on failure (for DRC diagnosis)
2026-07-11 route: resolve a pcbnew-capable python on Linux (fixes CI zone fill)
    kicad_python() fell back to bare 'python3', which under uv resolves to
    the venv interpreter with no pcbnew — so zone fill, hole keepouts and
    GND stitching silently no-oped in CI, leaving unconnected-pour DRC
    errors on every board. Prefer the python3 next to kicad-cli (distro
    pcbnew lives in its dist-packages); add a pcbnew import canary in CI.
2026-07-11 place_pcb: warn loudly when git describe fails; CI canary for it
    CI-built boards have been silently falling back to a name-only silk
    identifier (no revision) — surface the actual git error.
2026-07-11 ci: mark workspace safe.directory so git describe works in-container
    The bind-mounted workspace belongs to a different uid than the container
    user, so the board-identifier's git describe subprocess failed with
    'dubious ownership' and every CI board shipped a name-only silk stamp.
    The canary now hard-fails if describe breaks again.
2026-07-12 gitignore: keep stray KiCad project files out of modules/
2026-07-12 script: fact-check pass — fix diff-pair beat to match the measured copper
    - beat 8 rewritten: the pair IS coupled on all 12 boards (92-96% at
    0.3mm); the 'deferred to single-ended' log line covers only the
    mm-scale USB-C pad bridges — the beat is now 'I misread the log'
    - board.yaml doesn't hold USB pin choices (auto-derived) — fixed beat 6
    - on-screen command corrected to make.py --all; back-silk version stamp
    and CI/release beats added; shot list + accuracy notes updated
